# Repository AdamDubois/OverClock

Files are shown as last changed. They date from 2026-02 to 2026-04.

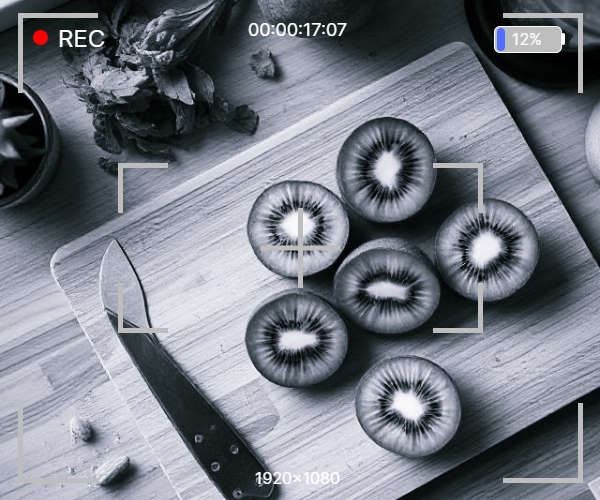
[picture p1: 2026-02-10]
Code/Codes_RaspPi/0-Desuet/Desuet_Codes_Test_RaspPi/img/imgKiwi.jpg

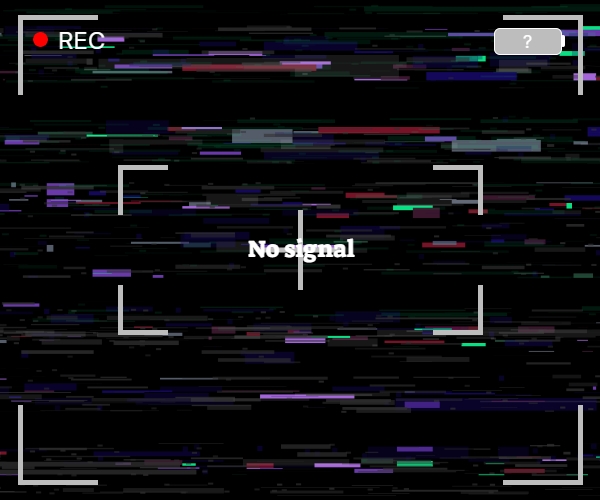
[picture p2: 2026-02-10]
Code/Codes_RaspPi/0-Desuet/Desuet_Codes_Test_RaspPi/img/NoSignal.jpg

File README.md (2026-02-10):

# Projet Bombe - InXtremis

## Description

Le projet Bombe à pour but de simuler une bombe pour un jeu d'évasion (escape game). Le joueur doit désamorcer la bombe en résolvant une série d'énigmes avant que le temps ne soit écoulé. Pour l'instant, le projet est en cours de développement et ne dispose pas encore de fonctionnalités complètes. Certains éléments de base ont été mis en place, mais ne sont pas intégrés dans un système de jeu complet. Par exemple, le contrôleur des lecteurs de cartes RFID est complètement fonctionnel et le contrôleur principal peut recevoir les données des lecteurs de cartes, mais il n'y a pas encore de logique de jeu pour utiliser ces données.

## Logique des composantes utilisées

**Contrôleur principal** : Il s'agit d'un Raspberry Pi 4 qui gère l'ensemble du système. Il reçoit les données des lecteurs de cartes RFID, des entrées/sorties (switchs et boutons) et peut contrôler d'autres composants tels que les LED, les buzzers, etc. Il est également responsable de la logique de jeu, c'est-à-dire de déterminer si les conditions pour désamorcer la bombe sont remplies ou non. Il gère également l'interface utilisateur qui sera sur un écran HDMI.

**Contrôleurs secondaires** : Il s'agit de trois ESP32-C3-WROOM-02U. Ils sont utilisés pour gérer la partie matérielle de la bombe, notamment les lecteurs de cartes RFID, les switchs, les boutons et les strips de DELs programmables. Ils communiquent avec le contrôleur principal via une I2C pour transmettre les données des entrées/sorties et recevoir les commandes pour contrôler les LED et autres composants.

## Fonctionnalités des différents ESP32

**ESP "RFID"** : Ce contrôleur est dédié à la gestion des lecteurs de cartes RFID. Il lit les données des cartes RFID et les transmet au contrôleur principal via I2C quand le Raspberry Pi en fait la demande.

**ESP "IO"** : Ce contrôleur gère les switchs et les boutons. Il lit l'état de ces entrées et les transmet au contrôleur principal via I2C quand le Raspberry Pi en fait la demande.

**ESP "LED"** : Ce contrôleur est responsable de la gestion des strips de DELs programmables. Il reçoit les commandes du contrôleur principal via I2C pour contrôler les LED en fonction de la logique de jeu.

## Architecture de ce dossier

Ce dossier contient les fichiers de code pour les différents composants du projet Bombe. Il est organisé de la manière suivante :
- `Code/` : Contient tous les fichiers de code pour les différents composants du projet, y compris le code pour le contrôleur principal (Raspberry Pi) et les contrôleurs secondaires (ESP32). Chaque composant a son propre sous-dossier pour organiser les fichiers de manière claire.
- `Documentation/` : Contient tous les documents liés au projet, tels que les diagrammes d'architecture, les schémas de câblage, les instructions d'installation et d'utilisation, les schémas électiques d'Altium, etc.
- `Matériel/` :  Contient les fichiers liés au matériel utilisé dans le projet, tels que les listes de composants, les schémas de câblage, les modèles 3D des boîtiers, etc.

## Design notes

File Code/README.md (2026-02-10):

# Projet Bombe - Code

## Description

Ce dossier contient tous les fichier de code pour les différents composants du projet. Il contient le code pour le contrôleur principal (Raspberry Pi) et les contrôleurs secondaires (ESP32). Chaque composant a son propre sous-dossier pour organiser les fichiers de manière claire.

## Architecture de ce dossier

Ce dossier contient les fichiers de code pour les différents composants du projet Bombe. Il est organisé de la manière suivante :
- `Codes_ESP32/` : Contient tous les fichiers de code pour les différents composants du projet, y compris le code pour le contrôleur principal (Raspberry Pi) et les contrôleurs secondaires (ESP32). Chaque composant a son propre sous-dossier pour organiser les fichiers de manière claire.
- `Codes_RaspPi/` : Contient tous les documents liés au projet, tels que les diagrammes d'architecture, les schémas de câblage, les instructions d'installation et d'utilisation, les schémas électiques d'Altium, etc.

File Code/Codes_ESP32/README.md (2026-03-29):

# Projet Bombe - Code/Codes_ESP32

## Description
Ce dossier contient les fichiers de code pour les différents ESP32 utilisés dans le projet Bombe. Chaque ESP32 a son propre sous-dossier pour organiser les fichiers de manière claire. Les codes sont écrits en C++ et utilisent la plateforme de développement PlatformIO pour faciliter la gestion des dépendances et la compilation.

## Architecture de ce dossier

Ce dossier contient les fichiers de code pour les différents composants du projet Bombe. Il est organisé de la manière suivante :
- `0-Desuet/` : Contient tous les projets de code qui ne sont plus utilisés ou qui sont obsolètes. Ces projets ont été créés avec un autre ESP comme base. Ils sont conservés à des fins de référence, mais ne sont plus maintenus ni utilisés dans le projet actuel.
- `ESP32_WROOM/` : Contient tous les projets de code pour les ESP32-WROOM utilisés dans le projet. Ces projets sont, pour la plupart, actifs et maintenus, et sont utilisés pour gérer les différentes fonctionnalités du projet Bombe, telles que la gestion des lecteurs de cartes RFID, des switchs, des boutons et des strips de DELs programmables. Chaque projet est organisé de manière claire pour faciliter la navigation et la compréhension du code.

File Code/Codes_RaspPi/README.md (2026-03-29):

# Projet Bombe - Code/Codes_RaspPi

## Description

Ici se trouvent tous les fichiers de code utilisés par le Raspberry Pi dans le projet Bombe.

## Architecture de ce dossier

Ce dossier contient les fichiers de code pour les différents composants du projet Bombe. Il est organisé de la manière suivante :
- `0-Desuet/` : Contient les codes qui ont été fait avant de choisir qu'on allait utiliser les ESP32. Ces codes sont donc fait pour communiquer avec tous les composants du projet, mais ils sont désuets et ne sont plus utilisés. Ils sont cependant gardés pour référence.
- `9Avril/` : Contient les projets de code qui seront utilisés pour la journée entrepreneuriale du 9 avril. Ces projets peuvent diverger du projet final, car ils sont faits pour être fonctionnels rapidement et pour être présentés lors de la journée entrepreneuriale. Ils sont cependant maintenus et peuvent être utilisés comme base pour le projet final. Après la journée entrepreneuriale, ces projets seront probablement fusionnés avec les autres projets actifs ou déplacés dans le dossier `0-Desuet/` s'ils ne sont plus pertinents pour le projet final.
- `Codes_Interactions_ESP/` : Contient les codes pour les interactions entre le Raspberry Pi et les ESP32, notamment la communication I2C. Il y a des codes uniquement pour envoyer et recevoir des données sur le bus I2C et il y en a pour tester uniqement les animations de DEL programmables sur le ESP32_DEL.
- `Enigmes/` : Contient les codes pour les différentes énigmes du projet Bombe. Ces codes sont utilisés pour gérer la logique des énigmes, les interactions avec les utilisateurs et les différentes fonctionnalités associées à chaque énigme. Chaque énigme a son propre sous-dossier pour organiser les fichiers de manière claire et faciliter la navigation.
- `Qt/` : Contient les fichiers de code pour l'interface graphique développée avec PyQt5. Cette interface permet de visualiser les données en temps réel, d'afficher les logs et d'interagir avec le système de manière plus intuitive.

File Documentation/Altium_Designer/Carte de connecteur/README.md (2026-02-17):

# Projet Bombe - Documentation/Altium_Designer

## Description

Cette section de la documentation regroupe l'ensemble des fichiers de conception électrique et de PCB réalisés avec le logiciel Altium Designer.
## Architecture de ce dossier

Elle contient les éléments suivants :
- Les schémas électriques du projet
- Les fichiers PCB (routage)
- Le dossier Bibliothèques contenant les composante utilisées dans les schémas et PCB

Les composants standards utilisés dans ce projet proviennent de la bibliothèque externe **Celestial Altium Library**.

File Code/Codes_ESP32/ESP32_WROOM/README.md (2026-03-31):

# Projet Bombe - Code/Codes_ESP32/ESP32_WROOM

## Description

Ce dossier contient les fichiers de code pour tous les projets de code pour les ESP32-WROOM utilisés dans le projet Bombe. Ces projets sont actifs et maintenus, et sont utilisés pour gérer les différentes fonctionnalités du projet Bombe, telles que la gestion des lecteurs de cartes RFID, des switchs, des boutons et des strips de DELs programmables. Chaque projet est organisé de manière claire pour faciliter la navigation et la compréhension du code.

## Architecture de ce dossier

Ce dossier contient les fichiers de code pour les projets ESP32-WROOM. Il est organisé de la manière suivante :
- `0-Desuet/` : Contient les projets obsolètes ou non utilisés. Ces projets ne sont plus maintenus et ne sont pas utilisés dans le projet Bombe, mais ils sont conservés pour référence ou pour des besoins futurs.
- `1-Codes_Tests/` : Contient des projets de test pour les ESP32-WROOM. Ces projets sont utilisés pour tester différentes fonctionnalités des ESP32-WROOM avant de les intégrer dans les projets principaux. Ces projets de test sont importants pour s'assurer que les composants fonctionnent correctement avant de les utiliser dans les projets principaux.
- `ESP_NEO_9AVRIL/` : Contient le projet du ESP qui gère les strips de DELs programmables. Ce projet reçoit des commandes I2C du Raspberry Pi pour contrôler les animations des strips de DELs programmables, et utilise la bibliothèque FastLED pour gérer les animations des DELs.
- `ESP-IO/` : Contient le projet du ESP qui gère les entrées/sorties, telles que les switchs et les boutons. Il utilise un IO expander pour gérer les entrées/sorties, et communique avec le Raspberry Pi en I2C pour envoyer les données des switchs et des boutons.
- `ESP-RFID/` : Contient le projet du ESP qui gère les lecteurs de cartes RFID. Ce projet lit les données des cartes RFID et les envoie les valeurs de UID des cartes en I2C au Raspberry Pi, quand il reçoit une requête de ce dernier.

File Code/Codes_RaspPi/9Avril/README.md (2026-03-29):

# Projet Bombe - Code/Codes_RaspPi/9Avril

## Description

Ici se trouvent les fichiers de code utilisés par le Raspberry Pi pour la journée entrepreneuriale du 9 avril. Ces codes sont fait pour fonctionner rapidement pour être utilisé lors de la journée entrepreneuriale. Les enigmes seront peut-être différentes de celles finales. Après la journée entrepreneuriale, ces codes seront peut-être modifiés pour s'adapter à la version finale du projet Bombe ou seront déplacées dans le dossier désuet du projet Bombe.

## Architecture de ce dossier

Ce dossier contient les fichiers de code pour la journée entrepreneuriale du 9 avril, notamment pour les interactions entre le Raspberry Pi et les ESP32 du projet Bombe. Il est organisé de la manière suivante :
- `RFID/` : Dossier contenant les codes pour l'énigme des lecteurs RFID. Il contient les codes pour lire les données des lecteurs RFID connectés aux ESP32 via I2C et pour envoyer des commandes I2C aux ESP32_DEL pour tester les animations de DEL programmables.
- `Switch/` : Dossier contenant les codes pour l'énigme des interrupteurs. Il contient les codes pour lire les données des interrupteurs connectés aux ESP32 via I2C et pour envoyer des commandes I2C aux ESP32_DEL pour tester les animations de DEL programmables.

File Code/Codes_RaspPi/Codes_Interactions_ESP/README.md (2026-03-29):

# Projet Bombe - Code/Codes_RaspPi/Codes_Interactions_ESP

## Description

Ici se trouvent les fichiers de code utilisés par le Raspberry Pi pour interagir avec les ESP32 du projet Bombe, notamment pour la communication I2C et les tests d'animations de DEL programmables sur le ESP32_DEL.

## Architecture de ce dossier

Ce dossier contient les fichiers de code pour les interactions entre le Raspberry Pi et les ESP32 du projet Bombe. Il est organisé de la manière suivante :
- `commande_I2C_test_led.py` : Code de test pour envoyer des commandes I2C au ESP32_DEL afin de tester les animations de DEL programmables. Utile pour vérifier que les commandes I2C sont correctement reçues et interprétées par le ESP32_DEL et que toutes les DELs fonctionnent correctement.
- `commandes_I2C.py` : Code qui permet d'envoyer ou demander des données à tous les ESP32 présents sur le bus I2C. Il suffit de spécifier l'adresse de l'ESP32 et la commande à envoyer. Utile pour envoyer des commandes spécifiques à un ESP32 ou pour demander des données à un ESP32 particulier de façon à s'assurer que la communication I2C fonctionne correctement avec chaque ESP32 individuellement.
- `read_RFID_I2C.py` : Code pour lire les données des lecteurs RFID connectés aux ESP32 via I2C. Lit les données en permanence et les affiche dans la console. Utile pour vérifier que les données des lecteurs RFID sont correctement reçues par le Raspberry Pi.
- `test_vitesse_IO.py` : Code de test pour mesurer la vitesse de lecture des données des ESP32 via I2C. Lit les données en permanence et affiche le temps de lecture dans la console. Utile pour vérifier que la communication I2C est suffisamment rapide pour les besoins du projet Bombe, notamment pour les énigmes qui nécessitent une lecture rapide des données des ESP32.

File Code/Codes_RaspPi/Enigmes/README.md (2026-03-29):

# Projet Bombe - Code/Codes_RaspPi/Enigmes

## Description

Contient les codes pour les différentes énigmes du projet Bombe. Ces codes sont utilisés pour gérer la logique des énigmes, les interactions avec les utilisateurs et les différentes fonctionnalités associées à chaque énigme. Chaque énigme a son propre sous-dossier pour organiser les fichiers de manière claire et faciliter la navigation.

## Architecture de ce dossier

Ce dossier contient les fichiers de code pour les différentes énigmes du projet Bombe, notamment pour les interactions entre le Raspberry Pi et les ESP32 du projet Bombe. Il est organisé de la manière suivante :
- `1/` : Dossier contenant les codes pour la première énigme du projet Bombe, qui est l'énigme des interrupteurs. Il contient les codes pour lire les données des interrupteurs connectés aux ESP32 via I2C et pour envoyer des commandes I2C aux ESP32_DEL pour tester les animations de DEL programmables.
- `2/` : Dossier contenant les codes pour la deuxième énigme du projet Bombe, qui est l'énigme des boutons et des strips de del ou il faut mettre les strips d'une couleur spécifique en fonction des boutons appuyés. Il contient les codes pour lire les données des boutons connectés aux ESP32 via I2C et pour envoyer des commandes I2C aux ESP32_DEL pour tester les animations de DEL programmables.

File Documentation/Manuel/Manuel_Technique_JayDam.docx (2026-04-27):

Adam Dubois

Jérémy Breault

Groupe: 2317

OverClock

Manuel technique présenté à :

Benoit Beaulieu

Louis-Philippe Gauthier

Simon Mailhot-Hébert

Étienne Desbiens

Département du génie électrique

Pour le cours

Projet de fin d’études

Cégep de Sherbrooke

2026-04-14

# 1. Description générale du produit

Ce projet consiste à la réalisation d’une mallette interactive qui intègre plusieurs dispositifs électroniques dans le but de proposer des énigmes à résoudre pour les utilisateurs. L’utilisateur devra interagir avec le système électronique et des composants physiques tout en étant guidé par une interface graphique à travers les jeux. Notre premier client est une entreprise de jeux d’évasion (InXtremis) qui propose différents scénarios dans la région de Sherbrooke. L’idée est de lui concevoir une mallette qui vient remplacer une mallette déjà existante, mais qui est endommagée et ne respecte plus les critères. Cette mallette est ajoutée à un module composé des trois barils et d’une structure en métal conçu par le client qui représente un module explosif simulé. Pour ce projet, les joueurs devront tenter leur chance et tester leur habilitées dans le but de résoudre différentes énigmes pour réussir à désamorcer un dispositif explosif simuler dans un temps allouer. La mallette agit comme élément central en structurant tous les modules ensemble. Placer au centre du produit, elle est le cerveau pour le fonctionnement du jeu, mais aussi un dispositif important pour aider les joueurs à mieux comprendre les énigmes tout en améliorant l’immersion.

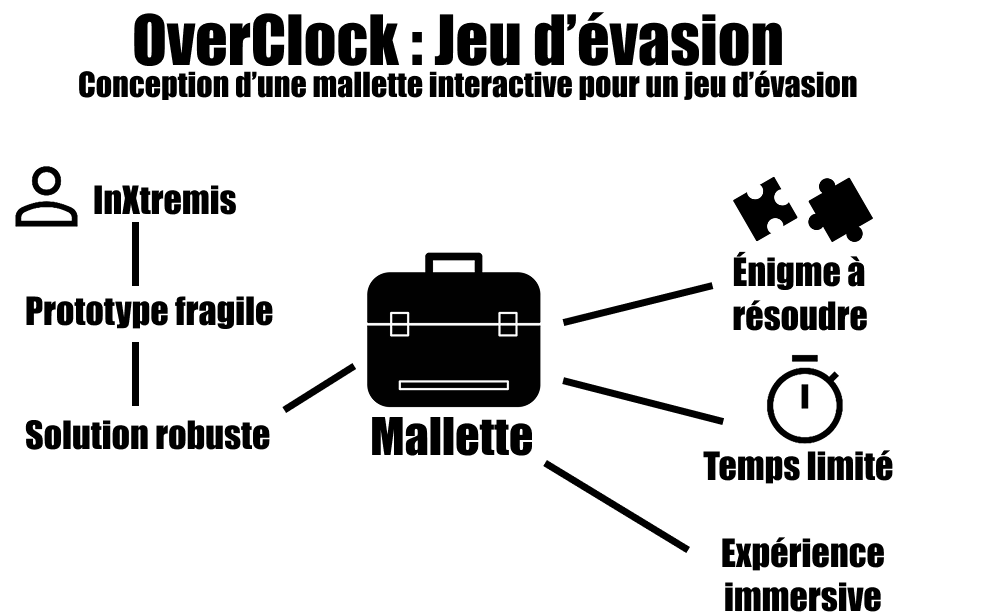
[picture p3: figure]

Figure 1 Vue d’ensemble du projet

# 2. Fonctionnement du produit

Le fonctionnement du projet est divisé en trois grandes parties. Nous avons le cerveau principal du projet, un Raspberry Pi 4, qui dirige les opérations à travers les différentes parties. Ensuite, trois ESP32 sont utilisés pour contrôler les différents modules composant les énigmes et pour finir, un écran HDMI est utilisé pour l’affichage de l’interface et pour faciliter le dépannage en cas de problème.

Le Raspberry Pi 4 envoie les directives à tous les modules connecter. Il contrôle l’écran via une communication HDMI et contrôle les trois ESP32 avec une communication de protocole I2C.

Le projet utilise trois ESP32 pour diriger différentes parties du module. Un ESP32 s’occupe du contrôle de toutes les bandes lumineuses. Un autre ESP32 s’occupe du contrôle des entrées des utilisateurs. Il contrôle les cinq boutons présents à l’intérieur de la mallette, les sept connecteurs banane et les quatre interrupteurs présents sur le module. Le dernier ESP32 s’occupe des quatre modules RFID. Le fonctionnement global repose sur une communication avec le Raspberry Pi 4. Chacun utilise le protocole I2C pour recevoir des commandes du Raspberry Pi 4. Le Raspberry Pi 4 agit comme maitre, tandis que les ESP32 agissent comme esclaves.

L’écran à l’intérieur de la mallette permet d’afficher le système d’exploitation du Raspberry Pi. Cet écran permet d’offrir une façon simple pour diagnostiquer un problème dans le Pi, mais permet aussi de venir changer le code pour les énigmes.

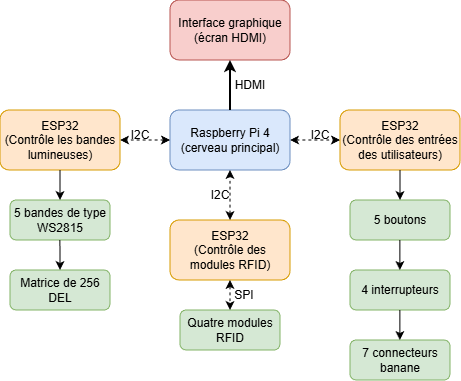
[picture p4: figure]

Figure 2 Diagramme de fonctionnement du projet

# 3. Procédure d’installation et d’opération

## Assemblage

1. Assembler les tuyaux de métal en fonction des numéros inscrits dessus.
2. Mettre les modules d’énigmes au bon emplacement en fonction des numéros.
3. Il faut mettre les barils à l’intérieur du châssis avant de le refermer complètement.
4. Passer tous les fils autour de la bombe de façon à tous les amener dans la mallette par le trou arrière.

## Branchement

Tous les câbles sont identifiés par un collant pour indiquer dans quel connecteur ils vont. Brancher tous les câbles à la bonne place sur la carte de connectique.

## Utilisation

Mettre l’interrupteur de l’alimentation principale (power supply) sur « I », puis activer la carte de connectique en position « ON ». Le système devrait alors s’alimenter et l’écran s’allumer automatiquement, avec le jeu en mode « Idle ». Pour lancer le jeu, il suffit d’envoyer une commande en UDP (à définir). Pour passer une énigme, appuyer trois fois sur le bouton vert en maintenant chaque appui pendant cinq secondes. Pour activer le mode débogage, appuyer cinq fois sur le bouton vert, toujours en maintenant chaque appui pendant cinq secondes.

## Dépannage

### Aucun démarrage

1. Vérifier que l’alimentation est bien fonctionnelle et sur la position « I ».
2. Vérifier que la carte de connecteur dans la mallette est bien à « ON ».
3. Vérifier la présence des trois indicatifs lumineux d’alimentation sur la carte de connecteur.
4. Tester chacun des fusibles présents sur la carte de connecteur.
5. Vérifier les connexions électriques des alimentations.
6. Remplacer l’alimentation avec une autre de 500 watts et plus si nécessaire.

### Écran non fonctionnel

1. Vérifier l’alimentation de l’écran.
2. Vérifier le câble HDMI.
3. Prendre un autre écran pour tester si nécessaire.

# 4. Contenu matériel

## Schéma électrique

La partie électronique du projet est composée de deux cartes électroniques. Nous avons la première carte qui s’occupe de raccorder tous les modules ensemble avec l’aide de plusieurs connecteurs. Celle-ci est située à l’intérieur de la mallette et représente la carte mère du projet. La deuxième carte est plus petite et s’occupe du branchement des quatre modules RFID. Elle est connectée à la carte mère avec deux câbles Ethernet (RJ45).

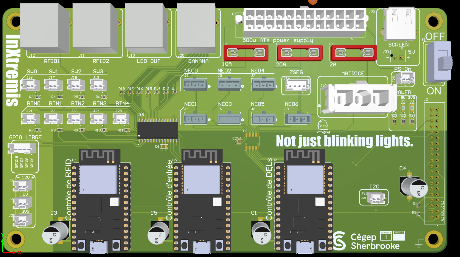
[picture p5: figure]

## Carte de connecteur

Figure 3 Carte mère

Le fonctionnement de la carte de connecteur repose sur cinq parties. La présente section passera à travers les parties pour vous expliquer le fonctionnement.

### Alimentation

L’alimentation du projet repose sur une alimentation ATX d’ordinateur d’une puissance de 500W et plus. Nous utilisons seulement le connecteur 24 broches, les sortie 3.3 volts, 5 volts ainsi que 12 volts pour l’alimentation des modules.

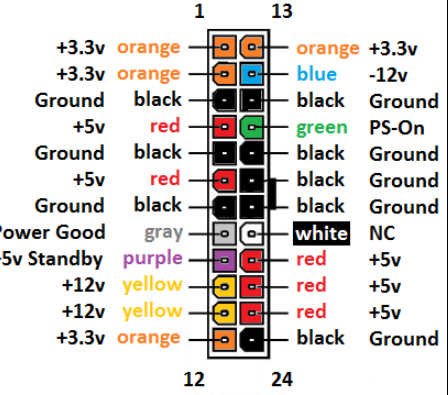
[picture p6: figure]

Figure 4 Répartition des broches – alimentation ATX

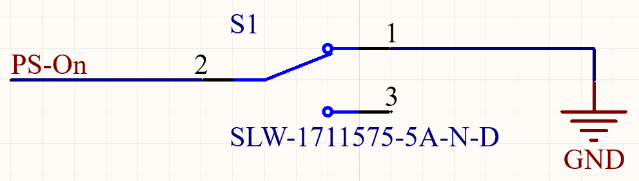
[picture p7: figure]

Le signal PS-ON nous permet de contrôler le fonctionnement de l’alimentation ATX. Si le signal est relié à la masse (GND), l’alimentation s’active. Les signaux 5 VUSB, PG, -5 V, et -12 V ne sont pas utiliser dans ce projet.

Figure 5 Interrupteur d’alimentation du système

Puisque le projet nécessite une grande puissance pour l’alimentation des bandes lumineuse, il est important de respecter la contrainte concernant les fusibles. Trois valeurs de fusible sont utilisées.

- 2 A pour la ligne 3,3 V;
- 10 A pour la ligne 12 V;
- 20 A pour la ligne 5 V;

Figure 6 Position des fusibles sur la carte

L’alimentation 12 V permet de fournir l’électricité aux six bandes lumineuses de type WS2815. L’alimentation 5 V alimentent les trois ESP32, le Raspberry Pi, la grande matrice de Del, le convertisseur de niveau logique et l’écran HDMI. L’alimentation 3.3 V alimente les quatre modules RFID et les différentes résistances de tirage vers le haut.

### Raspberry Pi

Le Raspberry Pi est connecté à la carte électronique via un câble nappe (ribbon câble) relié à un connecteur 40 broches. La communication avec les trois modules ESP32 s’effectue à l’aide du protocole I²C, permettant au Raspberry Pi d’envoyer des requêtes à chacun des dispositifs.

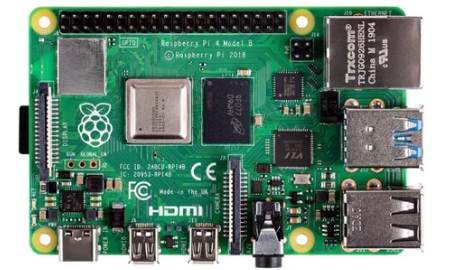
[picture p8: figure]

Figure 7 Raspberry Pi 4

### Esp32_Wroom (Contrôle de Del)

Le contrôle des bandes de DEL utilisées dans le projet est assuré par un ESP32 dédié. Celui-ci fonctionne comme esclave sur le bus I²C, avec l’adresse 0x12.

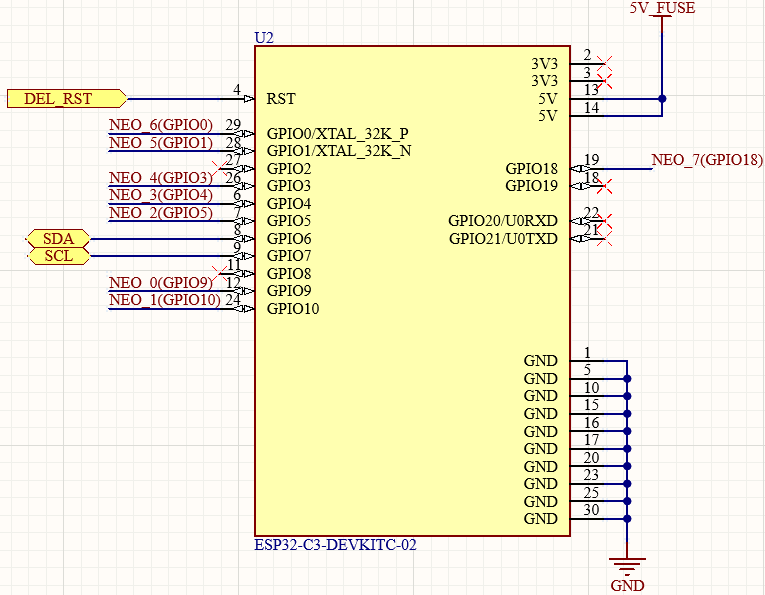
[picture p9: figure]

Figure 8 Schéma électrique de l’ESP32 pour le contrôle des bandes DEL

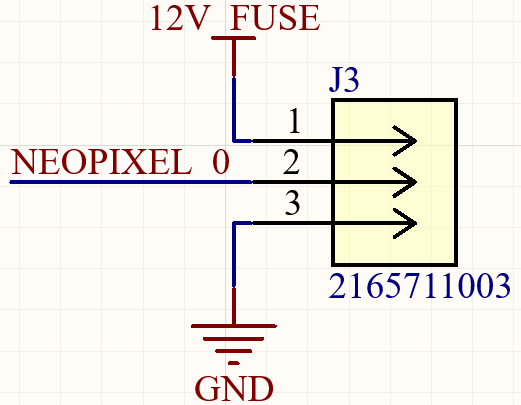
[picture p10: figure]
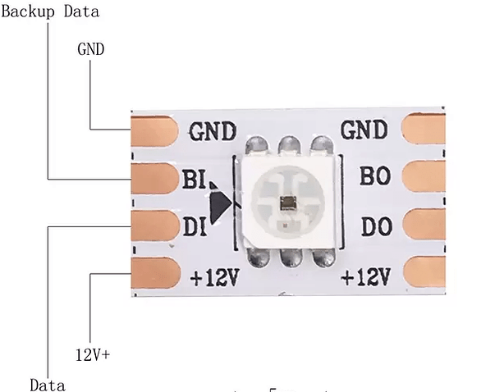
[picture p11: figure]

Les bandes DEL sont en 12 V avec un signal de données en 5 V, donc un convertisseur de niveau logique est utilisé pour les contrôler avec le contrôleur en 3,3 V.

Figure 9 Configuration des broches des WS2815

Sur le schéma de gauche, la configuration des broches pour le fonctionnement des bandes DEL (WS2815) montre le câblage pour leur fonctionnement. On peut voir se l’image de droite que nous avons seulement un connecteur de trois broches, cela est normal, puisque les signaux GND et Backup Data sont reliés ensemble.

### Esp32_Wroom (Contrôle de RFID)

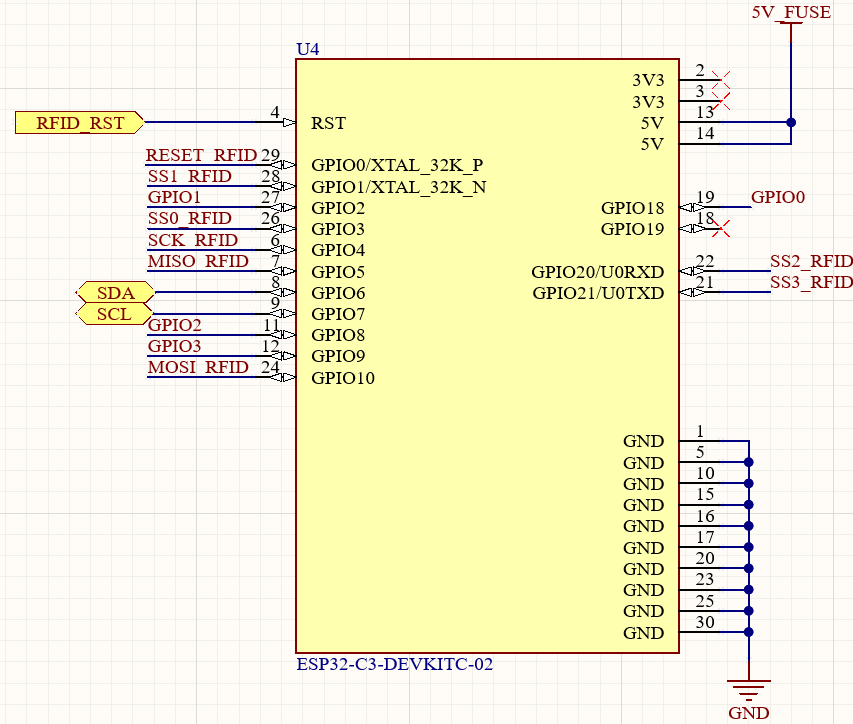
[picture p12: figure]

Le contrôle des quatre modules RFID est assuré par un ESP32 dédié. Celui-ci fonctionne comme esclave sur le bus I²C, avec l’adresse 0x11

Figure 10 Schéma électrique de l’ESP32 pour le contrôle des modules RFID

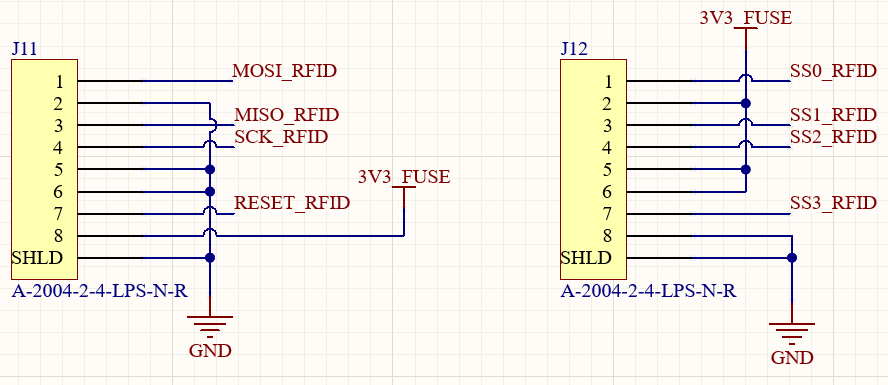
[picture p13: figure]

Les modules RFID sont connectés à une carte intermédiaire. Cette carte est ensuite reliée à notre carte principale avec deux câbles RJ45. Les câbles servent à la fois pour la communication et l’alimentation, en utilisant les paires torsadées pour réduire les interférences.

Figure 11 Câblage des signaux en paires torsadées

### Esp32_Wroom (Contrôle d’entrée)

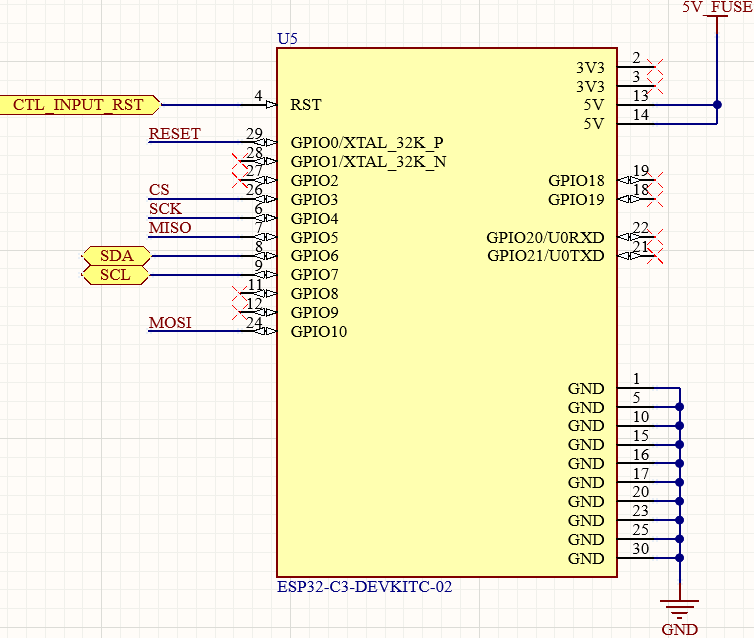
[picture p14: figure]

La gestion de toutes les entrées (boutons, interrupteurs et connecteurs) est assurée par un ESP32, qui en effectue la lecture. Celui-ci fonctionne comme esclave sur le bus I²C, avec l’adresse 0x10.

Figure 12 Schéma électrique de l’ESP32 pour le contrôle des entrées

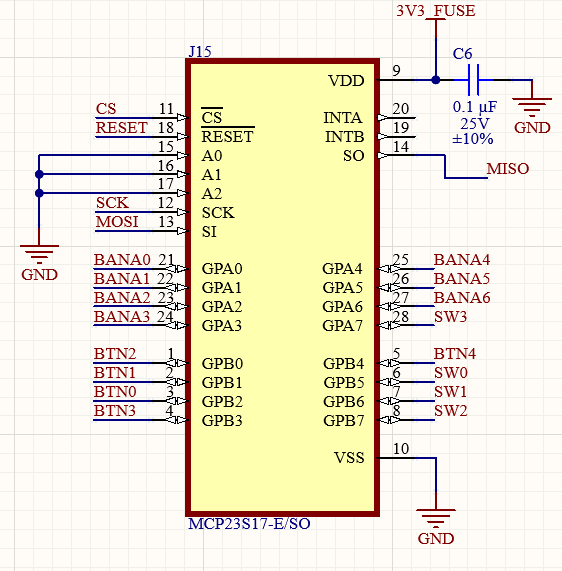
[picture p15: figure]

Comme il n’y a pas assez de GPIO sur le contrôleur, un expanseur est utilisé pour en ajouter 16 de plus. Il communique en SPI.

Figure 13 Expanseur 16 GPIO

Les cinq boutons présents à l’intérieur de la mallette ainsi que les quatre interrupteurs utilisent des connecteurs de type JST pour être raccordés à la carte de connexion.

Les connecteurs bananes sont raccordés à l’aide d’un câble RJ45.

Figure 14 Connecteurs des boutons et interrupteurs

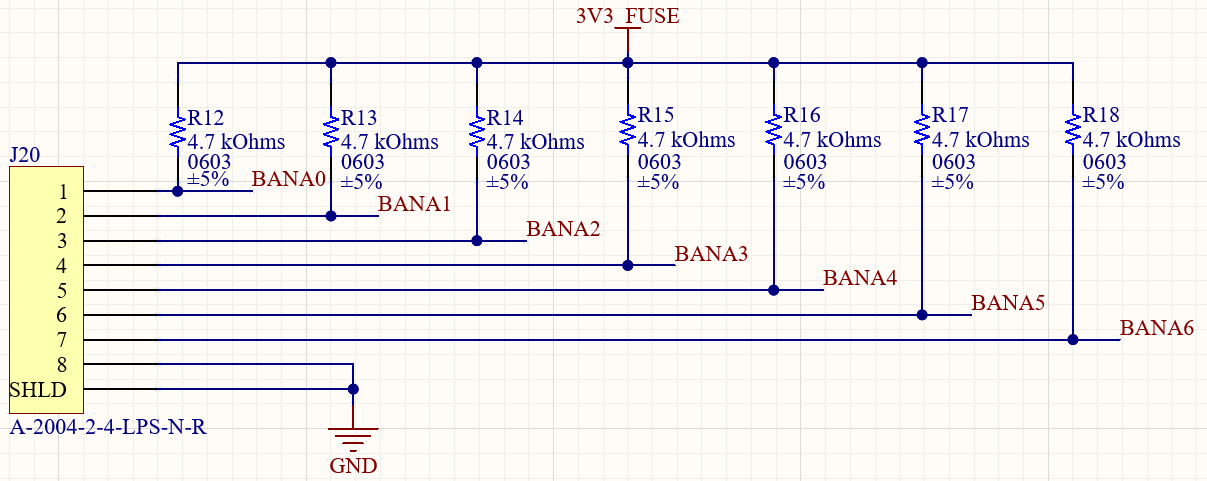
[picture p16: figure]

Figure 15 Connecteurs banane

## Carte pour module RFID

La deuxième carte pour le raccordement des quatre modules RFID est un moyen simple de nous permettre de venir diminuer le nombre de câbles qui doivent rejoindre la carte principale à l’intérieur de la mallette. Il connecte les deux câbles RJ45 et sépare le branchement pour venir raccorder les quatre modules proprement.

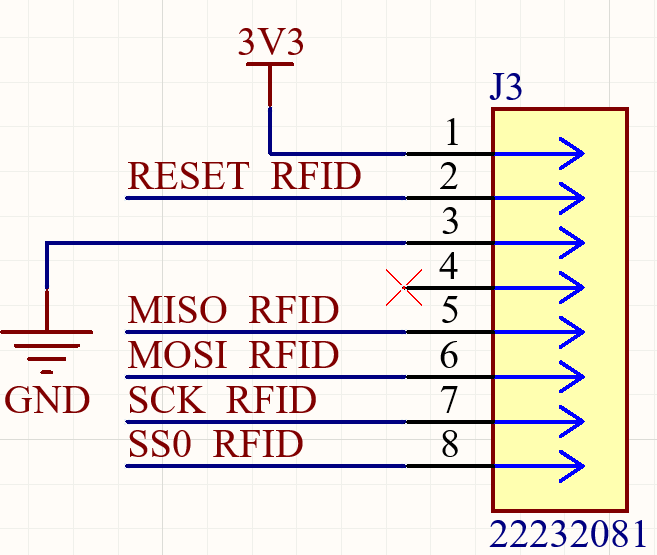
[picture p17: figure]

Figure 16 Câblage des modules RFID

L’alimentation de la carte provient de la ligne principale 3,3 V. Pour vérifier le bon fonctionnement, un indicateur lumineux est présent sur la carte afin de confirmer la présence de l’alimentation sur la carte.

# 5. Contenu logiciel

Pour obtenir plus d’information sur le contenu logiciel, simplement vous rendre sur la page git du projet.

Lien git : https://github.com/AdamDubois/OverClock.git

# 6. Procédure de développement

## Raspberry Pi

### Code

Dans cette partie, vous trouverez toutes les informations nécessaires pour modifier, exécuter et maintenir le code du projet. Le code est séparé en deux sections : le Raspberry Pi (maître du système) et les ESP32 (esclaves). La communication entre le Raspberry Pi et les ESP32 est effectuée via le protocole I2C.

Les fichiers sources sont disponibles sur le dépôt GitHub du projet :

Lien Git : https://github.com/AdamDubois/OverClock.git

1. Télécharger les fichiers sources (Git)

- Se rendre sur le dépôt GitHub du projet.
- Copier le lien du dépôt.
- Sur le Raspberry Pi (ou un ordinateur), cloner le dépôt :

git clone https://github.com/AdamDubois/OverClock.git

cd OverClock

Emplacements importants dans le dépôt :

- Code Raspberry Pi : Code/Codes_RaspPi/
- Code ESP32 : Code/Codes_ESP32/ESP32_WROOM/

2. Préparer le Raspberry Pi (installation des outils)

La partie Raspberry Pi est développée en Python. Avant d’exécuter les scripts, il faut installer les outils de base.

Mettre à jour le système :

sudo apt update

sudo apt upgrade -y

Installer les outils nécessaires :

sudo apt install -y git python3 python3-pip python3-venv

Activer l’I2C (si ce n’est pas déjà fait) :

- Ouvrir l’outil de configuration : sudo raspi-config
- Aller dans Interface Options → I2C → Enable
- Redémarrer le Raspberry Pi : sudo reboot

Vérifier que l’I2C est actif :

ls /dev/i2c*

Résultat attendu : /dev/i2c-1

3. Installer les librairies Python (requirements.txt)

Afin de standardiser l’installation des dépendances, un fichier requirements.txt est disponible au chemin suivant :

Code/Codes_RaspPi/requirements.txt

- Procédure d’installation

Se placer à la racine du dépôt :

cd /chemin/vers/OverClock

Créer un environnement virtuel Python (recommandé) :

python3 -m venv .venv

source .venv/bin/activate

pip install --upgrade pip

Installer les dépendances :

pip install -r Code/Codes_RaspPi/requirements.txt

4. Organisation du code Raspberry Pi

Le dossier Code/Codes_RaspPi/ est organisé en plusieurs sous-dossiers :

- Codes_Interactions_ESP/ : scripts de communication et tests (I2C, lecture RFID, reset ESP).
- Enigmes/ : logique des énigmes (ex. : Enigmes/1/, Enigmes/2/).
- 9Avril/ : version de démonstration/intégration (peut diverger de la version finale).

5. Exécuter des tests de communication (Raspberry Pi ↔ ESP32)

Les scripts de tests se trouvent dans :

Code/Codes_RaspPi/Codes_Interactions_ESP/

Test de communication I2C :

- Activer l’environnement virtuel : source .venv/bin/activate
- Aller au dossier : cd Code/Codes_RaspPi/Codes_Interactions_ESP
- Lancer : python3 commandes_I2C.py

Lecture RFID via I2C :

- Activer l’environnement virtuel : source .venv/bin/activate
- Aller au dossier : cd Code/Codes_RaspPi/Codes_Interactions_ESP
- Lancer: python3 read_RFID_I2C.py

6. Exécuter le code principal (Raspberry Pi)

Selon la version utilisée, le code d’intégration se trouve dans :

Code/Codes_RaspPi/9Avril/

Exemple d’exécution :

1. Activer l’environnement virtuel : source .venv/bin/activate
2. Se placer dans le dossier : cd Code/Codes_RaspPi/9Avril
3. Exécuter : python3 tout_v2.py

7. Développement ESP32 (compilation et téléversement)

Les projets ESP32 se trouvent dans :

Code/Codes_ESP32/ESP32_WROOM/

Projets principaux :

- ESP_NEO_9AVRIL/ : gestion des bandes DEL (commandes I2C reçues du Raspberry Pi).
- ESP-IO/ : gestion des entrées/sorties (boutons, interrupteurs, connecteurs bananes).
- ESP-RFID/ : gestion des lecteurs RFID (envoi des UID via I2C).
- 1-Codes_Tests/ : projets de test.
- Procédure générale
1. Ouvrir le projet dans Arduino IDE ou PlatformIO.
2. Sélectionner la carte ESP32-WROOM-C3-02U.
- Dans PlatformIO, le board est déjà choisi dans le projet. Pas besoin de lui spécifier une nouvelle fois.
3. Compiler le projet.
4. Téléverser via USB.
5. Vérifier la communication avec le Raspberry Pi à l’aide des scripts I2C ou regarder dans le terminal série si « DEBUG_MODE » est à « true » dans config.h.

8. Validation après modification

Après toute modification de code (Raspberry Pi ou ESP32), valider :

- Le Raspberry Pi démarre correctement.
- L’I2C est actif (/dev/i2c-1).
- Les ESP32 répondent via I2C.
- Les entrées fonctionnent (ESP-IO).
- Les DEL répondent correctement (ESP_NEO_9AVRIL).
- Les UID RFID remontent correctement (ESP-RFID).

### Interface

Dans cette partie, vous trouverez toutes les informations concernant la réalisation ainsi que le fonctionnement de l’interface graphique pour les énigmes

La conception de l’interface a été réaliser avec le langage de programmation QML sur l’application Qt Design Studio. Cette application est un environnement de développement d’interface graphique permettant à l’utilisateur qui l’utilise de concevoir son interface avec différent outil comme des composants visuels, des outils pour la mise en page et d’autres outils permettant la conception d’animation. L’utilisateur commence par créer un premier rendu de son interface et la programme ensuite. La présente partie vous guidera à travers l’installation de cette application exécutée sur un ordinateur.

#### Télécharger l’installateur Qt

  - Rendez-vous sur le site officiel de Qt pour créer votre compte avec une licence éducative Qt Educational Licenses (https://www.qt.io/development/qt-educational-license).
  - Connectez-vous sur le site Qt (https://www.qt.io/development/qt-educational-license).
  - Télécharger Qt Online Installer dans le portail Qt à la section downloads – Qt downloads.
  - Exécuter Qt Online Installer.
  - Suivez les étapes de l’installateur Qt.
    - Connectez-vous avec votre compte Qt.
    - Sélectionner le chemin pour l’installation de Qt.
    - Sélectionner Qt for desktop development et Custum Installation.
    - Dans le menu d’installation Visual Creation Tools, sélectionner Qt Design Studio 4.8.1.
    - Procéder à l’installation.

#### Premier pas avec l’application Qt Design Studio

  - Au lancement de l’application, vous aurez deux choix possibles, créé un nouveau projet ou ouvrir un projet existant. Pour l’instant, choisissez de créer un nouveau projet.
  - Dans les détails de la création du projet, il est important de choisir la bonne résolution pour l’affichage de son interface. Pour simplement tester, il est recommandé de mettre la même résolution que l’écran de son ordinateur ou de mettre plus petit.
  - Voici à quoi devrait ressembler votre fenêtre.

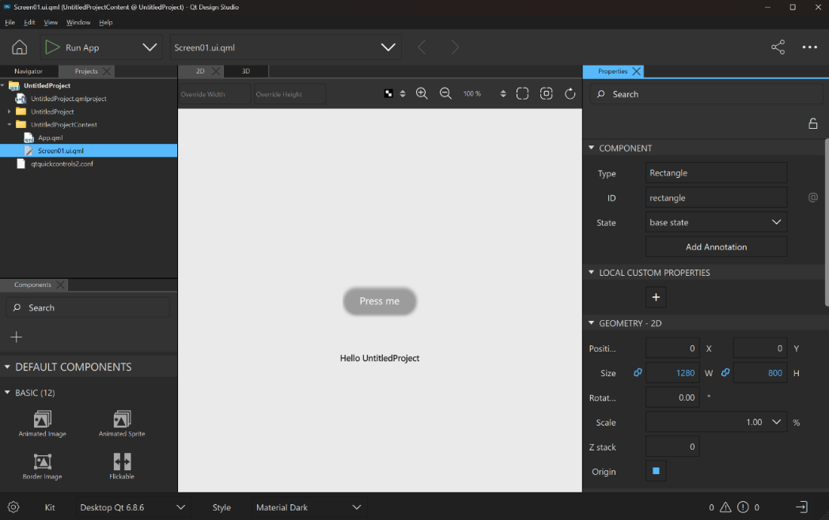
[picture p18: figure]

Figure 17 Écran initial Qt Design Studio

- Rendez-vous dans le ruban View en haut à gauche de la fenêtre et cocher Code dans le menu déroulant Views pour afficher le code de l’interface

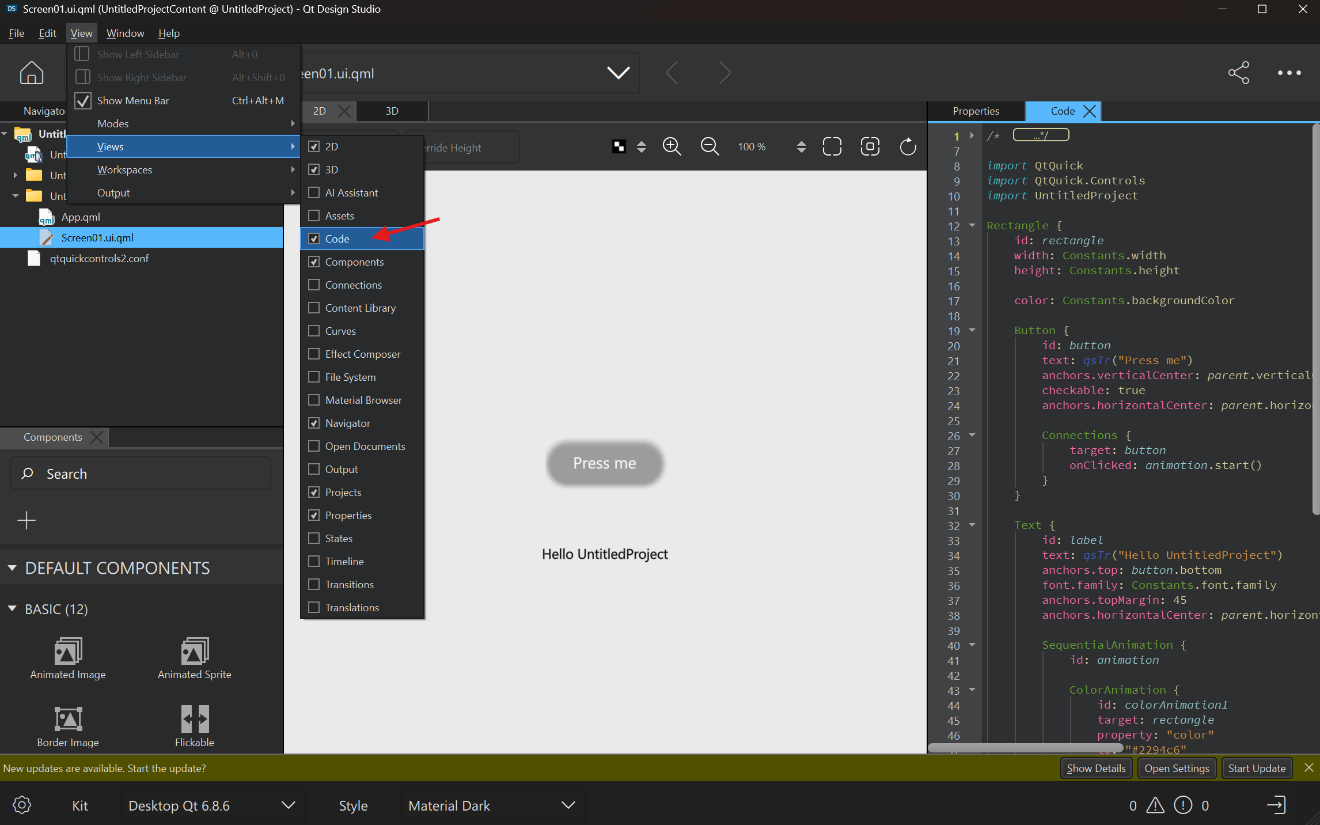
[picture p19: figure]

Figure 18 Afficher le code de l’interface

- La visualisation du code permet de voir comment les différents composants de l’interface sont représentés en langage de programmation QML. Cela nous permet de venir modifier des propriétés plus précisément. Je vous recommande d’aller consulter des exemples et tutoriels sur le site officiel de Qt (Qt Doc (https://doc.qt.io/qt-6/qtexamplesandtutorials.html)).
- Dans le bas à gauche de l’écran, vous trouverez tous les composants disponibles à la construction de votre interface.

Figure 19 Composants Qt

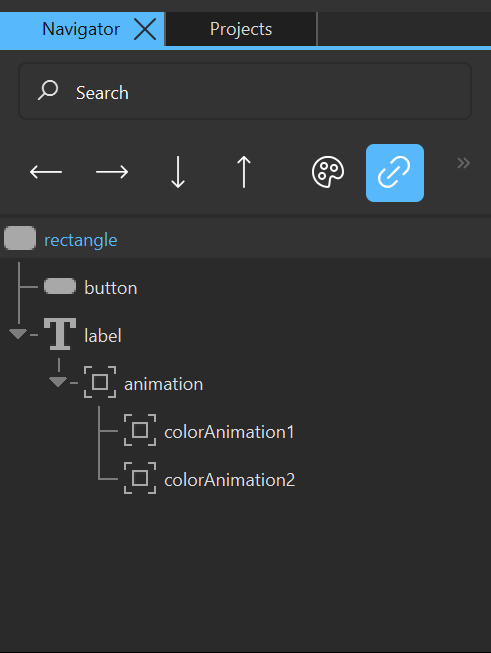
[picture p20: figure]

- Dans la section gauche de votre fenêtre, vous trouverez la section navigation qui permet de visualiser la structure hiérarchique de l’interface. Vous trouverez aussi la section projet qui permet de voir les différents fichiers de votre interface.

Figure 20 Structure Qt

- Vous pouvez tester votre première interface en cliquant sur le bouton Run App
- Vous êtes maintenant plus familiarisée avec l’application Qt Design Studio, je vous recommande maintenant de passer à l’étape suivante pour reprendre ou modifier le projet déjà existant

#### Utilisation du projet existant

Dans le dossier Git du projet, rendez-vous au chemin « OverClock\Code\Codes_RaspPi\Qt\Interface_9avril\OverClockUI\OverClock ». C’est ici que ce trouve tous les fichiers responsables au fonctionne de l’interface graphique pour le jeu d’évasion.

Vous pouvez ouvrir ce fichier dans Qt Design Studio.

Voici la liste des fichiers importants pour la modification ou la création du jeu.

- Le fichier main.py permet d’initialiser l’interface graphique et de structurer le fonctionnement de celle-ci en démarrant le serveur de réception de données (JsonReceive), puis lance l’interface. Il s’occupe de la réception des données du jeu pour les transmettre à l’interface.
- Le fichier jsonreceive.py permet de gérer la communication entre l’interface et les données envoyer par le Raspberry Pi comme, le démarrage du jeu, énigme, état des RFID. Il inclut un moniteur interne pour simuler le temps restant au jeu.
- Dans le dossier « OverClockContent », vous trouverez tous les fichiers pour la création de l’interface.
- Le fichier « App.qml » permet la gestion de l’affichage des différentes interfaces du jeu en fonction.
- Les fichiers commençant par le terme « Enigme », représente chacun une énigme en particulier.
- Le fichier « IdleScreen » est l’interface lors du démarrage et lorsque le jeu est inactif.
- Le fichier « FinScreen » est l’interface affichée lorsque le jeu est terminé.

Pour lancer l’interface, il suffit de lancer le fichier « main.py ».

#### Fonctionnement de l’interface sur le Raspberry Pi

Cette section vous montrera comment faire fonctionner l’interface sur le Raspberry Pi 4.

Pour faire fonctionner l’interface, il est nécessaire d’installer les bibliothèques requises sur le Raspberry Pi 4 à l’aide de la commande « sudo apt install ».

- libpyside6-py3-6.8
- python3-pyside6.qtqml
- Python3-pyside6.qtcore
- python3-pyside6.qtquick
- Python3-pyside6.qtopengl
- python3-pyside6.qtgui
- python3-pyside6.qtwidgets
- qml6-module-qtquick qml6-module-qtquick-window -y
- qml6-module-qtquick-controls qml6-module-qtquick-layouts -y
- qml6-module-qtquick-timeline -y

Il est recommandé de développer l’application sur un ordinateur plutôt que directement sur le Raspberry Pi 4.

# 7. Listes de matériel et coûts

Figure 21 Détail des coûts

# 8. Modifications et améliorations

1. Il manque un GPIO sur le PCB pour connecter le bouton vert de l’énigme des connecteurs bananes.
2. Le boitier contenant les lecteurs RFID est trop petit ce qui cause des interférences et empêche un lecteur fiable et durable des cartes RFID
3. Les connecteurs pour les bandes DEL ont été faites pour des bandes DEL de 3 connecteurs. Les bandes DEL qu’on utilise actuellement ont 4 connecteurs. Il faudrait donc changer ces connecteurs
4. Changer les connecteurs JST sur la carte pour des connecteurs MOLEX. Les JST sont assez difficile à assembler et sont beaucoup plus difficile à débrancher que des MOLEX.
5. Le bus RX et TX du ESP RFID est utilisé par des CS. Il est donc impossible de Serial Print des informations en même temps d’obtenir les valeurs des lecteurs.

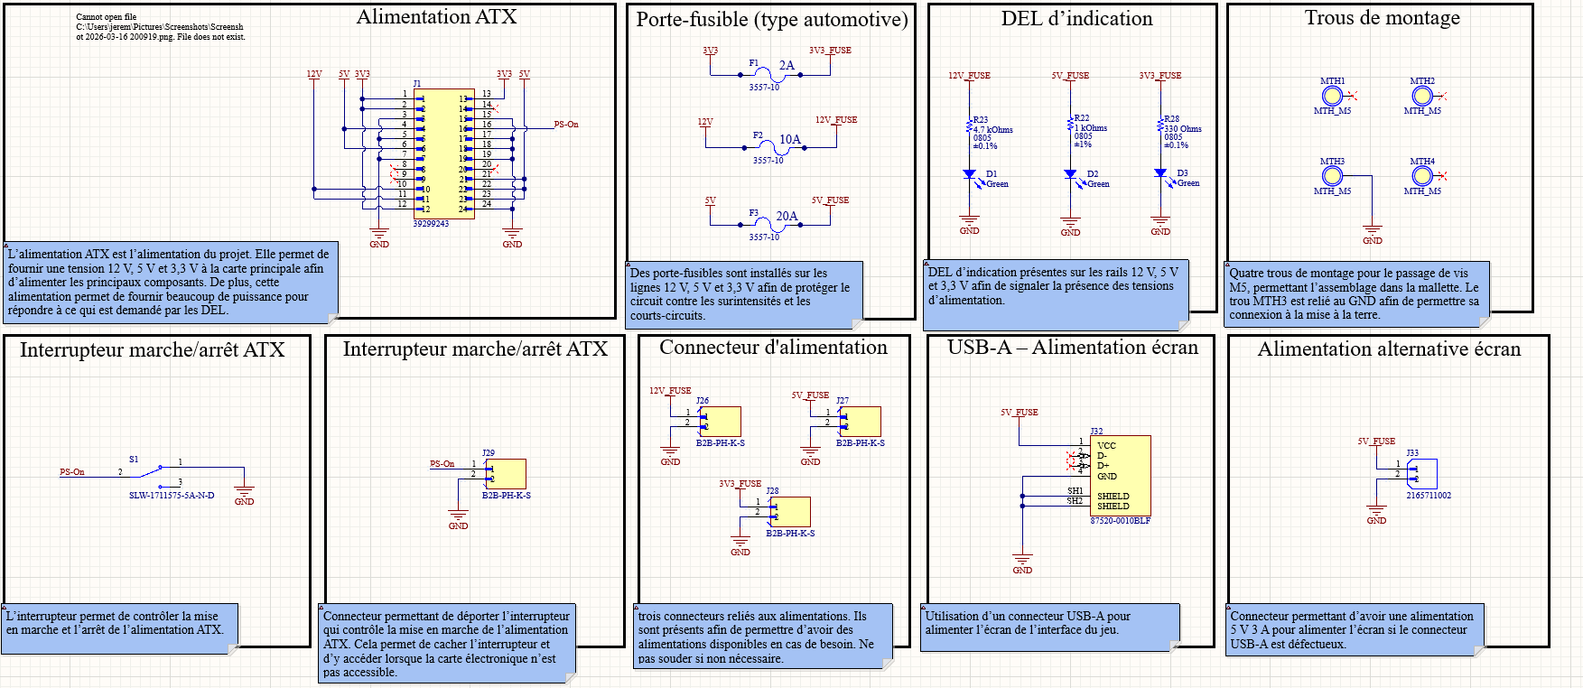
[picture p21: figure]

# Documents annexes

Figure 22 Alimentation

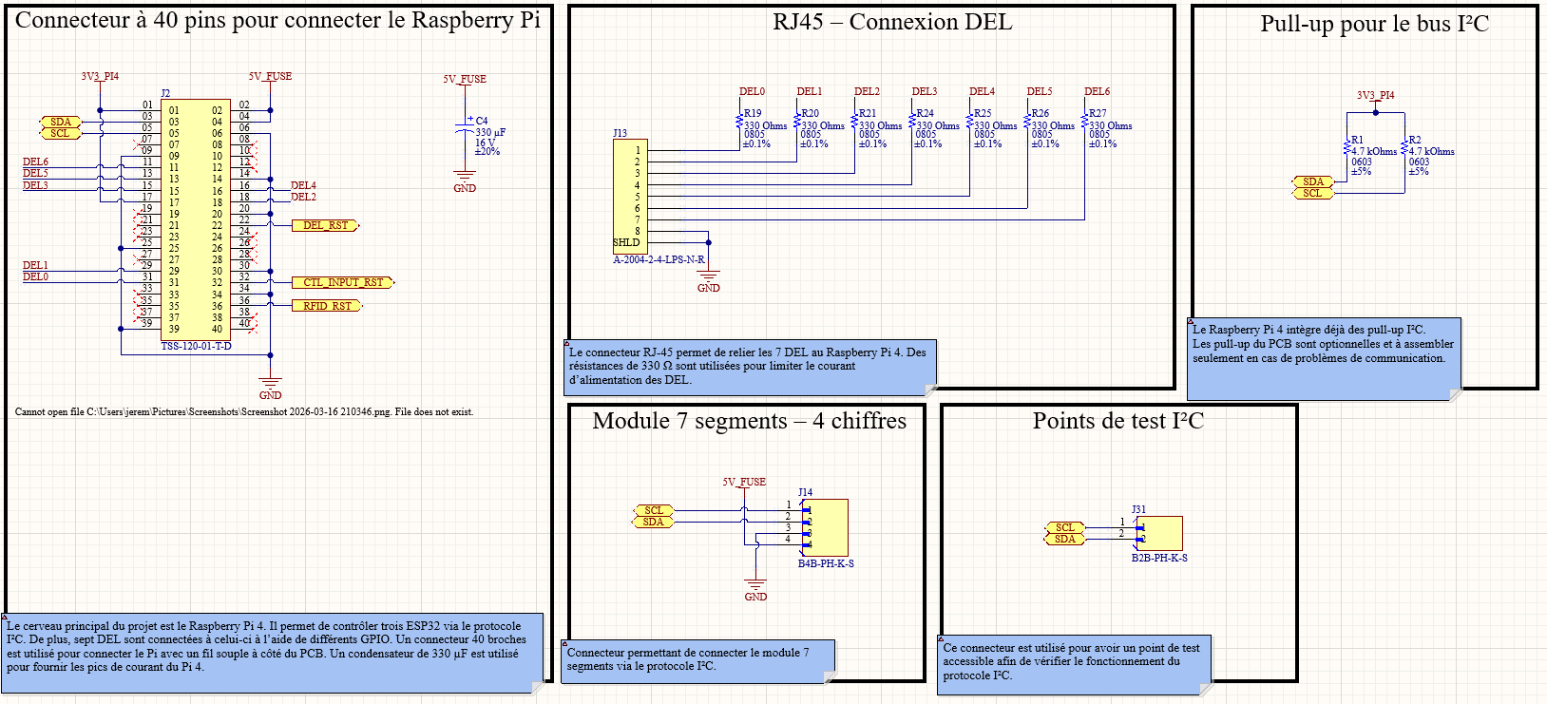
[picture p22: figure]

Figure 23 Raspberry Pi 4

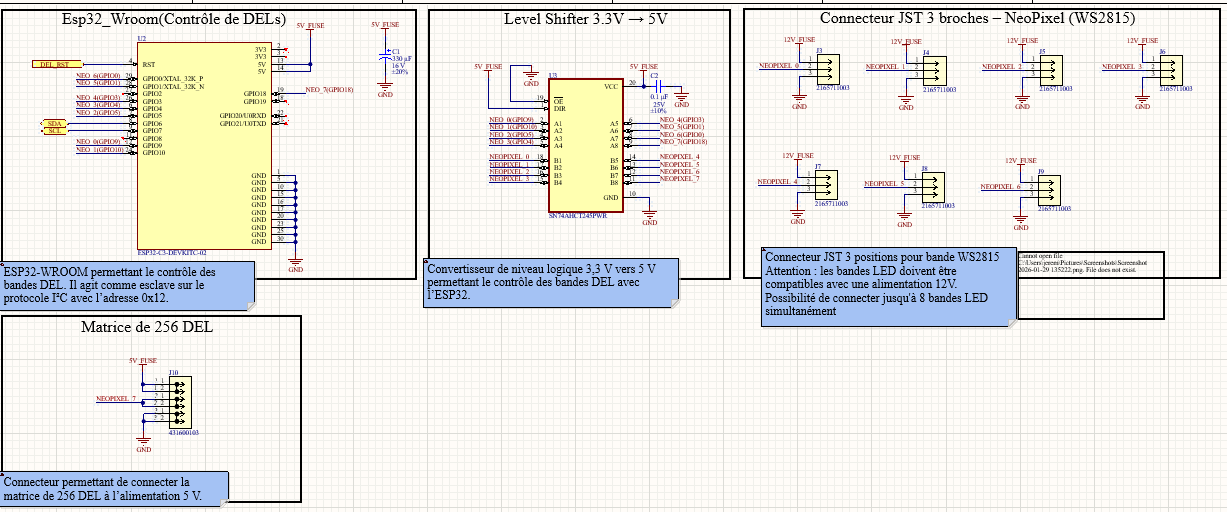
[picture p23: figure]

Figure 24 Contrôle de DEL

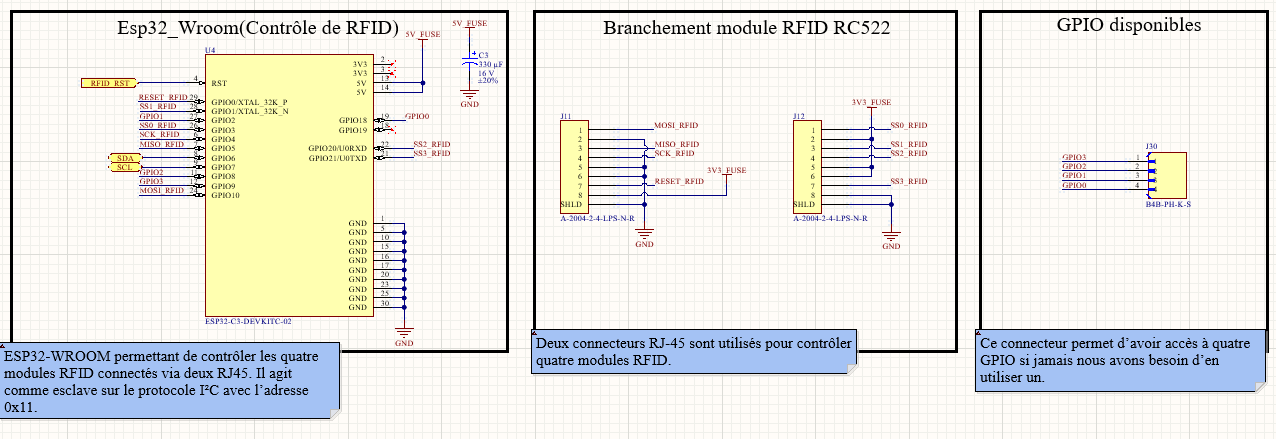
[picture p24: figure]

Figure 25 Contrôle de RFID

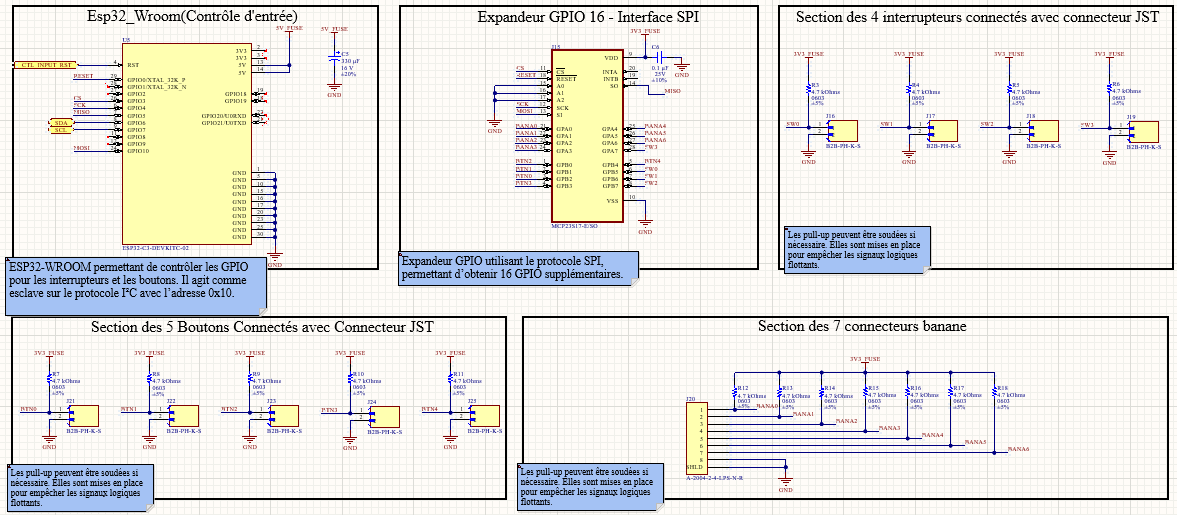
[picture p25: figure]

Figure 26 Contrôle d'entrée

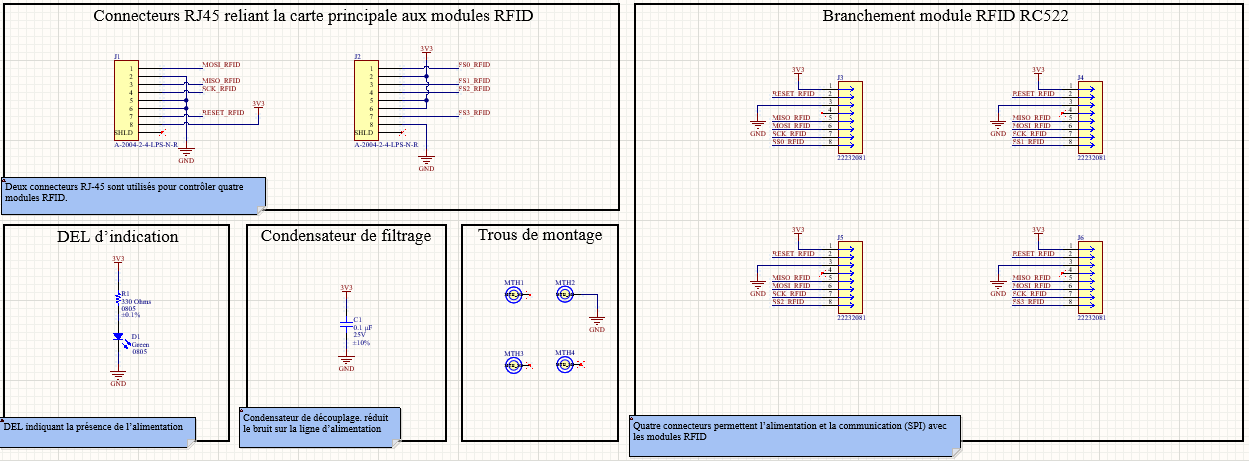
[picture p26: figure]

Figure 27 Carte RFID

Nom du Projet Manuel Technique

OverClock Manuel Technique

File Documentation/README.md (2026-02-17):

# Projet Bombe - Documentation

## Description

Ici vous trouverez tous les documents liés au projet Bombe, y compris les diagrammes d'architecture, les schémas de câblage, les instructions d'installation et d'utilisation, les schémas électiques d'Altium, etc. Ce dossier est destiné à fournir une documentation complète pour le projet Bombe afin de faciliter la compréhension et la mise en œuvre du projet pour tous les membres de l'équipe et les futurs contributeurs.

## Architecture de ce dossier

Ce dossier contient les fichiers de documentation pour les différents composants du projet Bombe. Il est organisé de la manière suivante :
- `Altium_Designer/` : Contiendra les schémas électriques et les PCB conçus avec Altium Designer pour les différents composants du projet.
- `Références/` : Contient toutes les références utiles à la compréhension du système et des schémas électriques (documents techniques, fiches techniques, notes, etc.).

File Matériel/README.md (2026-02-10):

# Projet Bombe - Matériel

## Description

Ce dossier contient les informations sur le matériel nécessaire pour réaliser le projet de la bombe. Il inclut les composants électroniques, les outils et les matériaux requis pour assembler et faire fonctionner la bombe.

## Architecture de ce dossier

Ce dossier contient les fichiers liés au matériel utilisé dans le projet Bombe. Il est organisé de la manière suivante :

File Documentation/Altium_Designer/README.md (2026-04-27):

# Projet Bombe - Altium Designer

## Description
Vous trouverez ici tous l'ensemble des fichiers liés à la conception électronique réalisée avec la plateforme Altium Designer 

Vous trouverez les schémas, les bibliothèques de composants, et les deux conceptions pour les cartes électroniques du projet.

## Structure du dossier
- Facture - contiens les factures reliées à la conception des cartes électroniques.
- Bibliothèques - regroupe les bibliothèques des composantes utilisées dans le projet.
- Carte de connecteur - tous les fichiers pour la conception de la carte électronique principale du projet.
- Carte RFID - contiens les fichiers pour la conception de la carte électronique pour le contrôle des modules RFID.

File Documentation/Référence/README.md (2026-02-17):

# Projet Bombe - Documentation/Référence

## Description

Ce dossier contient les documents techniques utilisés pour le projet :

## Architecture de ce dossier

Ce dossier contient les fichiers de documentation pour les différents composants du projet Bombe. Il est organisé de la manière suivante :
- Fiches techniques des composants
- Note utile pour la réalisation du projet
- Documents techniques

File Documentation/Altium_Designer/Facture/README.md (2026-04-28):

# Projet Bombe - Altium Designer/Facture
## Description
Vous trouverez ici les factures reliées à la conception des cartes électroniques du projet OverClock.

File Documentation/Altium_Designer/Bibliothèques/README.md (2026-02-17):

# Projet Bombe - Documentation/Altium_Designer/Bibliothèques

## Description

Ce dossier contient l’ensemble des bibliothèques utilisées pour le projet. Les composants sont organisés en différentes catégories.

Les composants standards utilisés dans ce projet proviennent de la bibliothèque externe **Celestial Altium Library**.

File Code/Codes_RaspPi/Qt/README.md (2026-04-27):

# Projet Bombe - Code/Code_RaspPi/Qt

## Description

Ce dossier contient le code Qt utilisé sur le Raspberry Pi pour tester l’interface graphique du projet Bombe.

Vous trouverez une première interface graphique pour les trois énigmes proposées à la soirée entrepreneuriales.

## Architecture de ce dossier

- test/ : contient une première version d’interface utilisateur très simple servant aux tests et à la validation de base.
- Interface_9avril : contient l'ensemble des fichiers pour le fonctionnement de l'interface graphique pour les trois énigmes proposées à la soirée entrepreneuriales.

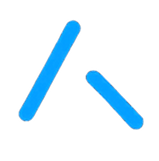
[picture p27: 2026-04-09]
Code/Codes_RaspPi/Qt/Interface_9avril/OverClockUI/OverClock/OverClockContent/images/deuxLignes.png

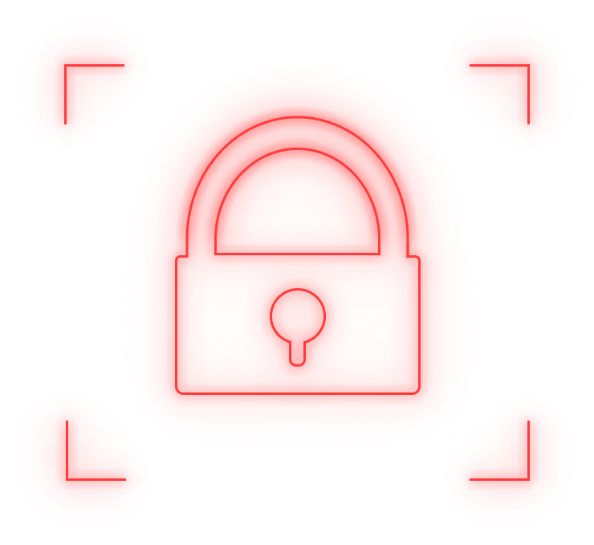
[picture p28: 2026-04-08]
Code/Codes_RaspPi/Qt/Interface_9avril/OverClockUI/OverClock/OverClockContent/images/CadenasRouge.png

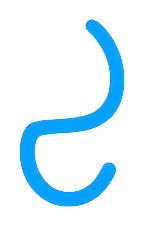
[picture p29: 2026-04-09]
Code/Codes_RaspPi/Qt/Interface_9avril/OverClockUI/OverClock/OverClockContent/images/genredeS_code.png

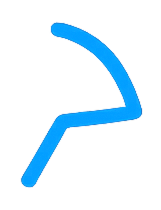
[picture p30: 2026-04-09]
Code/Codes_RaspPi/Qt/Interface_9avril/OverClockUI/OverClock/OverClockContent/images/interogtion_code.png

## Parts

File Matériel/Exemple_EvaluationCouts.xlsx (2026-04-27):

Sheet: Liste
Commande de composants électroniques | Description | Lien Web chez le fournisseur | Prix unitaire | Quantité | Transport | Total
Raspberry Pi | Raspberry Pi 4 Model B/4GB | https://www.pishop.ca/product/raspberry-pi-4-model-b-4gb/?searchid=0&search_query=Pi+4%60 | 139.95 $ | 1 | 11.83 $ | 151.78 $
ESP32-C3-DevKitC-02U | WiFi Development Tools - 802.11 ESP32-C3 general-purpose development board, embeds ESP32-C3-WROOM-02U-N4, 4 MB flash, with pin header | https://www.mouser.ca/ProductDetail/Espressif-Systems/ESP32-C3-DevKitC-02U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 | 12.00 $ | 3 | 0.00 $ | 36.00 $
1500 Protector Case | Mallete Pelican modèle 1500 | https://www.pelican.com/ca/en/product/cases/1500?sku=1500-001-110 | 232.95 $ | 1 | 0.00 $ | 232.95 $
0.1inch HDMI LCD (B) (with case) | 10.1inch Capacitive Touch Screen LCD (B) with Case, 1280×800, HDMI, IPS Screen, Low Power | https://www.waveshare.com/10.1inch-hdmi-lcd-b-with-case.htm | 110.99 $ | 1 | 38.00 $ | 148.99 $
PCBs | Cartes électronique pour le projet. Comprends la carte principale et celle pour les RFID | https://jlcpcb.com/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 | 8.12 $ | 1 | 50.00 $ | 58.12 $
Commande de composants électroniques | Digikey + Mouser | Commande | 237.16 $ | 1 |  | 237.16 $
 |  |  |  |  |  | 0.00 $
 |  |  |  |  |  | 0.00 $
 |  |  |  |  |  | 0.00 $
 |  |  |  |  |  | 0.00 $
 |  |  |  |  |  | 0.00 $
 |  |  |  |  |  | 0.00 $
 |  |  |  |  |  | 0.00 $
 |  |  |  |  |  | 0.00 $
 |  |  | Sous-total |  |  | 865.00 $
 |  |  | Taxes |  |  | 129.75 $
 |  |  | Grand Total |  |  | 994.75 $

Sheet: Commande
Commande de composants
Description | Prix unitaire | Quantité | Total item | Fournisseur | # Modèle pour commande | Hyperlien pour commande (si disponible) ou soumission | Prix hors taxe | taxe | Livraison | Total
CAP CER 0.1UF 16V X7R 0805, CAP CER 0.1UF 25V X7R 0805 | 0.18 $ | 10 | 1.80 $ | mouser.ca | 80-C0805C104M4R | https://www.mouser.ca/ProductDetail/KEMET/C0805C104M4RACTU?qs=VOOUd%252Bza08rn8%252BKVjcWMVQ%3D%3D | 184.27 $ | 12.90 $ | 40.00 $ | 237.16 $
Single Color LEDs SMD 0805 GREEN 560nm | 0.75 $ | 7 | 5.25 $ | mouser.ca | 645-5975316507F | https://www.mouser.ca/ProductDetail/Dialight/5975316507F?qs=gTYE2QTfZfT42%252BCs2jfhAg%3D%3D
Fuse Holder T/H 2 IN 1 AUTO BLDE HOLDER, YELLOW 20A | 1.97 $ | 5 | 9.85 $ | mouser.ca | 534-3557-20 | https://www.mouser.ca/ProductDetail/Keystone-Electronics/3557-20?qs=iR2ablhfrmF%2FWhSZXEYN7g%3D%3D
Fuse Holder T/H 2 IN 1 AUTO BLDE HOLDER, RED 10A | 2.03 $ | 5 | 10.15 $ | mouser.ca | 534-3557-10 | https://www.mouser.ca/ProductDetail/Keystone-Electronics/3557-10?qs=iR2ablhfrmF7t%2F4oUDx%252B%2Fw%3D%3D
Headers & Wire Housings 24 CRT VERT HEADER | 5.27 $ | 3 | 15.81 $ | mouser.ca | 538-39-29-9243 | https://www.mouser.ca/ProductDetail/Molex/39-29-9243?qs=DQ3LI50eFWbK%252BUDchTyndA%3D%3D
Headers & Wire Housings .100 Shrouded Terminal Strip | 5.69 $ | 3 | 17.07 $ | mouser.ca | 200-TSS12001TD | https://www.mouser.ca/ProductDetail/Samtec/TSS-120-01-T-D?qs=rU5fayqh%252BE0fe8yiSPJ69Q%3D%3D
Headers & Wire Housings Micro-Fit+ RA Header 3 Circuits Black | 3.28 $ | 10 | 32.80 $ | mouser.ca | 538-216571-1003 | https://www.mouser.ca/ProductDetail/Molex/216571-1003?qs=aP1CjGhiNiG31dsw841K9g%3D%3D
Headers & Wire Housings VERT HDR SMC 3P without board lock | 2.89 $ | 5 | 14.45 $ | mouser.ca | 538-43160-0103 | https://www.mouser.ca/ProductDetail/Molex/43160-0103?qs=P7cO%252B%252BFDLzTsTkAe5N5p%252Bg%3D%3D
Interface - I/O Expanders 16bit Input/Output Exp SPI interface | 2.59 $ | 3 | 7.77 $ | mouser.ca | 579-MCP23S17-E/SO | https://www.mouser.ca/ProductDetail/Microchip-Technology/MCP23S17-E-SO?qs=usxtMOJb1RzJScThsWtScg%3D%3D
B2B-PH-K-S | 0.15 $ | 20 | 3.00 $ | mouser.ca | 306-B2BPHKSLFSNPP | https://www.mouser.ca/ProductDetail/JST-Commercial/B2B-PH-K-SLFSN?qs=cdbOS8ANM9AlozzPlOt72g%3D%3D
Thick Film Resistors - SMD 0603 4K7ohm 5% Anti Surge AEC-Q200 | 0.22 $ | 24 | 5.28 $ | mouser.ca | 755-ESR03EZPJ472 | https://www.mouser.ca/ProductDetail/ROHM-Semiconductor/ESR03EZPJ472?qs=DyUWGjl%252BcVtkRvvrQHOTyA%3D%3D
Thick Film Resistors - SMD 0805 Anti-Surge Res. 0.1%, 330ohm | 0.32 $ | 12 | 3.84 $ | mouser.ca | 667-ERJ-PB6B3300V | https://www.mouser.ca/ProductDetail/Panasonic/ERJ-PB6B3300V?qs=eFOtW6xYNWFhIWygg2og3A%3D%3D
Thin Film Resistors - SMD 1KOhms 0805 0.25W 100ppm 1% Hi Pwr Anti-Sulfur | 0.15 $ | 5 | 0.75 $ | mouser.ca | 708-RNCP0805FTD1K00 | https://www.mouser.ca/ProductDetail/SEI-Stackpole/RNCP0805FTD1K00?qs=FESYatJ8odKy9z1hnQn%252Bhg%3D%3D
Thick Film Resistors - SMD 0805 Anti-Surge Res. 0.1%, 4.7Kohm | 0.32 $ | 3 | 0.96 $ | mouser.ca | 667-ERJ-PB6B4701V | https://www.mouser.ca/ProductDetail/Panasonic/ERJ-PB6B4701V?qs=eFOtW6xYNWEHNAylU4xJeQ%3D%3D
SLW-1711575-5A-N-D | 0.61 $ | 3 | 1.83 $ | mouser.ca | 179-SLW17115755AND | https://www.mouser.ca/ProductDetail/Same-Sky/SLW-1711575-5A-N-D?qs=IKkN%2F947nfCI%2FYNFg6qyCw%3D%3D
Bus Transceivers Tri-State Octal Bus A 595-SN74AHCT245PW A 595-SN74AHCT245PW | 1.04 $ | 3 | 3.12 $ | mouser.ca | 595-SN74AHCT245PWR | https://www.mouser.ca/ProductDetail/Texas-Instruments/SN74AHCT245PWR?qs=vxEfx8VrU7DerZZBYgV7Yw%3D%3D
CONN MOD JACK 8P8C R/A SHIELDED | 1.19 $ | 12 | 14.26 $ | DigiKey | AE10387-ND | https://www.digikey.ca/en/products/detail/assmann-wsw-components/A-2004-2-4-LPS-N-R/2183638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
CONN RCPT USB2.0 TYPEA 4POS R/A | 0.97 $ | 3 | 2.91 $ | DigiKey | 609-1045-ND | https://www.digikey.ca/en/products/detail/amphenol-cs-fci/87520-0010BLF/1001359
CONN HEADER VERT 8POS 2.54MM | 0.49 $ | 6 | 2.94 $ | DigiKey | WM4206-ND | https://www.digikey.ca/en/products/detail/molex/0022232081/26679?s=N4IgTCBcDaIOoFkAsYAMA2AtAOQCIgF0BfIA
RES SMD 330 OHM 0.1% 1/4W 0805 | 0.21 $ | 3 | 0.63 $ | Digikey | P20537CT-ND | https://www.digikey.ca/en/products/detail/panasonic-industry/ERJ-PB6B3300V/6213320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
CAP ALUM 330UF 20% 16V SMD | 0.71 $ | 10 | 7.10 $ | Digikey | 732-8525-1-ND | https://www.digikey.ca/en/products/detail/w%C3%BCrth-elektronik/865060353008/5728120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
CONN HEADER VERT 4POS 2MM | 0.16 $ | 6 | 0.96 $ | Digikey | 455-1706-ND | https://www.digikey.ca/en/products/detail/jst-sales-america-inc/B4B-PH-K-S/926613
FUSE AUTO 2A 32VDC BLADE ATO/ATC | 0.60 $ | 3 | 1.80 $ | Digikey | 0287002.H-ND | https://www.digikey.ca/en/products/detail/littelfuse-inc/0287002-H/3104041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
FUSE AUTO 10A 32VDC BLADE ATO | 0.60 $ | 3 | 1.80 $ | Digikey | F11064-ND | https://www.digikey.ca/en/products/detail/littelfuse-inc/0287010-H/3104045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
FUSE AUTO 20A 32VDC BLADE ATO | 0.60 $ | 3 | 1.80 $ | Digikey | F11066-ND | https://www.digikey.ca/en/products/detail/littelfuse-inc/0287020-H/3104047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
CONN RCPT HSG 3POS 3.00MM | 0.46 $ | 10 | 4.64 $ | Digikey | 900-2157591003-ND | https://www.digikey.ca/en/products/detail/molex/2157591003/14668554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
MICRO-FIT PLUS FEMCRPTER 20-24AW | 0.13 $ | 50 | 6.29 $ | Digikey | WM26579CT-ND | https://www.digikey.ca/en/products/detail/molex/2064600021/10209736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
CONN HSG RCPT 3POS 7.50MM BLACK | 0.78 $ | 2 | 1.56 $ | Digikey | WM18464-ND | https://www.digikey.ca/en/products/detail/molex/0444412003/300097?s=N4IgTCBcDaIOoFkCMAOALANjQWgHIBEQBdAXyA
TERM BLADE FEMALE 14-16AWG TIN | 0.09 $ | 10 | 0.90 $ | Digikey | WM9174CT-ND | https://www.digikey.ca/en/products/detail/molex/0433750001/592656?s=N4IgTCBcDaIOoFkCcBGA7AFgMIBUC0AcgCIgC6AvkA
GPIO RIBBON CABLE FOR RASPBERRY | 2.95 $ | 1 | 2.95 $ | Digikey | 1528-2235-ND | https://www.digikey.ca/en/products/detail/adafruit-industries-llc/1988/7241480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

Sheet: Infos
Les cellules en bleues doivent se calculer automatiquement (utiliser une formule).
Dans l'évaluation des coûts, ne pas oublier:
Les cartes de développements
Les PCB (prévoir 50$ comme frais de livraisons)
Les connecteurs
Les câbles ou fils si longues distances
Les boîtiers
Ne pas mettre les composants discrets (résistances, condensateurs, etc) de moins de $2.00

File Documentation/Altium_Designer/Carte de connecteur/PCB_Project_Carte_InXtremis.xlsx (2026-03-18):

Comment | Description | Designator | Footprint | LibRef | Quantity
330 µF | CAP ALUM 330UF 20% 16V SMD | C1, C3, C4, C5 | CAP ALSMD 8.3MM H10.5MM | 865060353008 | 4
0.1 µF | CAP CER 0.1UF 25V X7R 0805 | C2, C6 | CAP 0805_2012 | 0805Y0250104KXT | 2
Green | LED GREEN 0805 SMD | D1, D2, D3 | LED 0805_2012 GREEN | 5975316507F | 3
3557-10 |  | F1, F2, F3 | FUSE_3557-10 | 3557-10 | 3
39299243 | Conn Wire to Board HDR 24Power POS 4.2mm Solder ST Top Entry Thru-Hole Tray | J1 | MOLEX_39299243 | 39299243 | 1
TSS-120-01-T-D | Connector Header Through Hole 40 position 0.100 (2.54mm) | J2 | SAMTEC_TSS-120-01-T-D | TSS-120-01-T-D | 1
2165711003 | Micro-Fit+ Vertical Header, Through Hole, 3.00mm Pitch, Single Row, 3 Circuits, Matte Tin (Sn) Plating, Glow-Wire Capable, Black | J3, J4, J5, J6, J7, J8, J9 | CONN_2165710003-SD_03_MOL | 2165711003 | 7
431600103 | Sabre Vertical Header, 3 Circuits, Glow-Wire Capable, PCB Thickness 1.60mm, without Board Lock | J10 | CONN_431600001-SD_V_03_MOL | 431600103 | 1
A-2004-2-4-LPS-N-R | CONN MOD JACK 8P8C R/A SHIELDED | J11, J12, J13, J20 | ASSMANN A-2004-2-4-LPS-N-R | A-2004-2-4-LPS-N-R | 4
B4B-PH-K-S |  | J14, J30 | JST_B4B-PH-K-S | B4B-PH-K-S | 2
MCP23S17-E/SO | Microchip MCP23S17-E/SO,16-channel 16bit I/O Exp&er 5MHz,Serial-SPI,28-Pin SOIC | Microchip Technology Inc. MCP23S17-E/SO | J15 | SOIC127P1030X265-28N | MCP23S17-E/SO | 1
B2B-PH-K-S | Connector Header Through Hole 2 position 0.079 (2.00mm) | J16, J17, J18, J19, J21, J22, J23, J24, J25, J26, J27, J28, J29, J31 | JST_B2B-PH-K-S | B2B-PH-K-S | 14
87520-0010BLF | Conn Data USB TypeA Socket 4Cnts RightAngle ThruHole White 1.57mmPCB | Amphenol FCI (Amphenol CS) 87520-0010BLF | J32 | AMPHENOL_87520-0010BLF | 87520-0010BLF | 1
2165711002 |  | J33 | MOLEX_2165711002 | 2165711002 | 1
4.7 kOhms | RES SMD 4.7K OHM 5% 1/4W 0603 | R1, R2, R3, R4, R5, R6, R7, R8, R9, R10, R11, R12, R13, R14, R15, R16, R17, R18 | RES 0603_1608 | ESR03EZPJ472 | 18
330 Ohms | RES SMD 330 OHM 0.1% 1/4W 0805 | R19, R20, R21, R24, R25, R26, R27, R28 | RES 0805_2012 | ERJ-PB6B3300V | 8
1 kOhms | RES 1K OHM 1% 1/4W 0805 | R22 | RES 0805_2012 | RNCP0805FTD1K00 | 1
4.7 kOhms | RES SMD 4.7K OHM 0.1% 1/4W 0805 | R23 | RES 0805_2012 | ERJ-PB6B4701V | 1
SLW-1711575-5A-N-D | Switch Slide ON ON SPDT Raised Slide 0.3A 50VDC 10000Cycles PC Pins Thru-Hole | S1 | SW_SLW-1711575-5A-N-D | SLW-1711575-5A-N-D | 1
ESP32-C3-DEVKITC-02 | The ESP32-C3-DEVKITC-02 Evaluation Board from Espressif Systems is a development platform for wireless applications, offering 802.11 b/g/n Wi-Fi and Bluetooth (BLE) connectivity at 2.4GHz. Powered by the ESP32-C3-WROOM-02 module, it features a 32-bit RISC | U2, U4, U5 | XCVR_ESP32-C3-DEVKITC-02 | ESP32-C3-DEVKITC-02 | 3
SN74AHCT245PWR |  | U3 | SOP65P640X120-20N | SN74AHCT245PWR | 1

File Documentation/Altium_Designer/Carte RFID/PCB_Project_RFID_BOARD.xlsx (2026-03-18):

Comment | Description | Designator | Footprint | LibRef | Quantity
0.1 µF | CAP CER 0.1UF 25V X7R 0805 | C1 | CAP 0805_2012 | 0805J0250104KXT | 1
Green | LED GREEN 0805 SMD | D1 | LED 0805_2012 GREEN | 5975316507F | 1
A-2004-2-4-LPS-N-R | CONN MOD JACK 8P8C R/A SHIELDED | J1, J2 | ASSMANN A-2004-2-4-LPS-N-R | A-2004-2-4-LPS-N-R | 2
22232081 |  | J3, J4, J5, J6 | CONN_A-6373-08A_MOL | 22232081 | 4
330 Ohms | RES SMD 330 OHM 0.1% 1/4W 0805 | R1 | RES 0805_2012 | ERJ-PB6B3300V | 1

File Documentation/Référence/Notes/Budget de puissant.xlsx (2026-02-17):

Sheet: Budget de Puissance
Budget de puissance |  |  |  |  |  |  | Puissance total @12V (W) |  | Courant total @12V (A)
Composant | Qté | Tension (V) | Courant unitaire (A) | Courant total (A) | Puissance (w) | Notes | 145.62 |  | 12.135
Raspberry Pi 4 | 1 | 5 | 3 | 3 | 15 | 3A peak | Puissance total @5V (W) |  | Courant total @5V (A)
ESP32-C3 | 3 | 5 | 0.1 | 0.3 | 1.5 | ESP32 consommation max | 85.62 |  | 17.124
 |  |  |  |  |  |  |  | 91.08510638
7 Del | 7 | 5
Matrice de 256 | 256 | 5 | 0.054 | 13.824 | 69.12 | puissance max en blanc |  | 5.465106383
5 Strip Del 40 Del | 5 | 12 | 0.025 | 5 | 60
 |  |  |  | 0 |  |  |  | 1.821702128
 |  |  |  | 0
 |  |  |  | 0
 |  |  |  | 0
 |  |  |  | 0 |  |  |  | 263.8251489

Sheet: Calcul thermique
Calcul thermique

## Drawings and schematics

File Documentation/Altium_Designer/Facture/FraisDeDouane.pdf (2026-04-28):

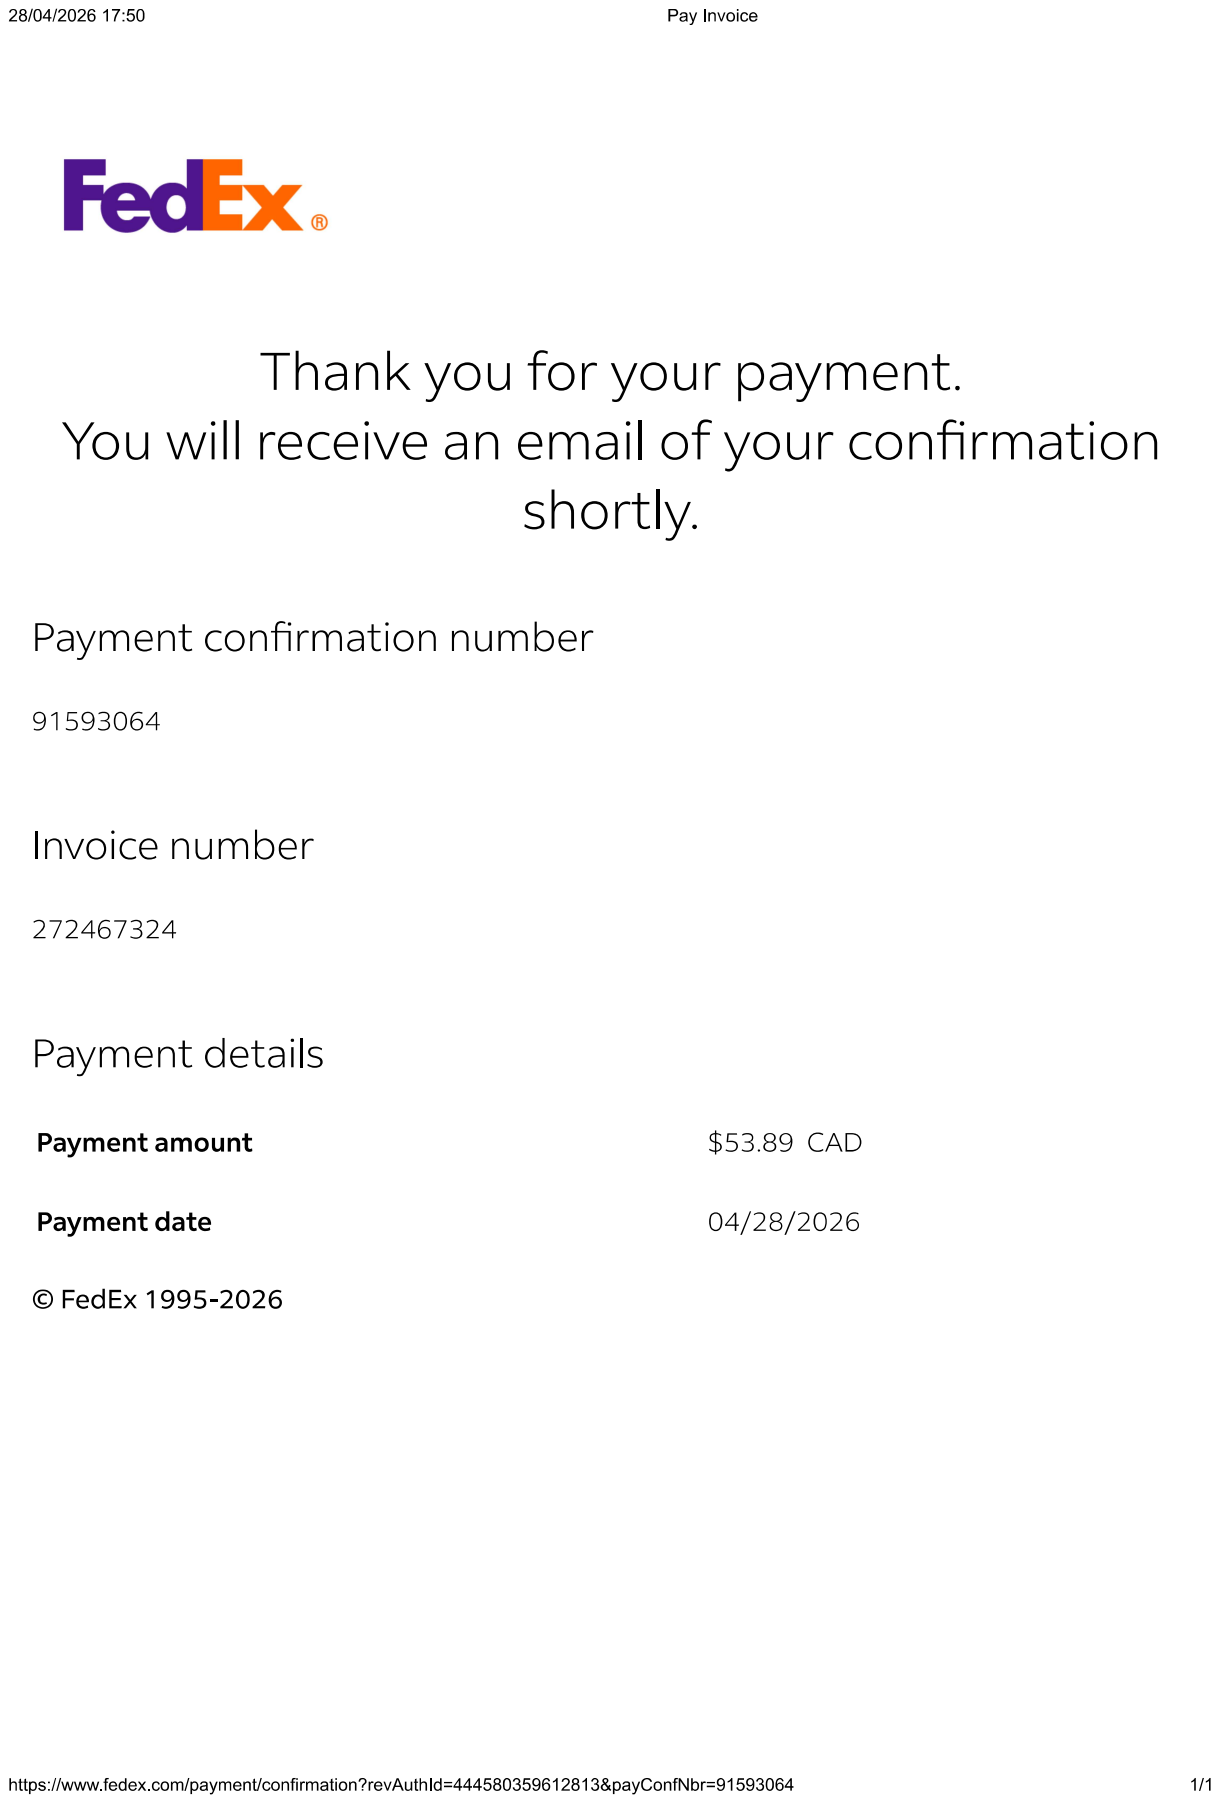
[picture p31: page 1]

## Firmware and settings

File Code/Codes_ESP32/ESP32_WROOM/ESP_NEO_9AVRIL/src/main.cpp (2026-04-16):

#include <Arduino.h>
#include <FastLED.h> //Bibliothèque pour la gestion des LEDs
#include <Wire.h> //Communication I2C entre les esp32 et le PI
#include <string.h> //Pour la manipulation des string
#include <ArduinoJson.h>

#define SLAVE_ADDR 0x12  // Adresse de l'esclave

#define SDA_PIN 6
#define SCL_PIN 7

#define DATA_PIN_E1_0     9   // Pin de données pour la bande de LEDs
#define DATA_PIN_E1_1     10  // Pin de données pour la bande de LEDs
#define DATA_PIN_E1_2     5  // Pin de données pour la bande de LEDs
#define DATA_PIN_E1_3     4  // Pin de données pour la bande de LEDs
#define DATA_PIN_E1_4     3  // Pin de données pour la bande de LEDs
#define DATA_PIN_E2       0  // Pin de données pour la bande de LEDs

#define NB_STRIP 6      // Nombre de bandes de LEDs
#define NB_LEDS_STRIP_E1_0 60 // Nombre de LEDs sur la bande 1
#define NB_LEDS_STRIP_E1_1 60 // Nombre de LEDs sur la bande 2
#define NB_LEDS_STRIP_E1_2 60 // Nombre de LEDs sur la bande 3
#define NB_LEDS_STRIP_E1_3 60 // Nombre de LEDs sur la bande 4
#define NB_LEDS_STRIP_E1_4 60 // Nombre de LEDs sur la bande 5
#define NB_LEDS_STRIP_E2 17 // Nombre de LEDs sur la bande 6

String g_stringOfAllData = "";
int g_compteur = 0; // Compteur pour flasher la strip sélectionnée
int g_stripSelected = -1; // -1 signifie qu'aucune strip n'est sélectionnée, sinon 0 à 4 pour les strips E2_0 à E2_4
int g_couleurStripSelected[3] = {0, 0, 0}; // Couleur de la strip sélectionnée (R, G, B)
int g_animationIndex = -1; // -1 signifie aucune animation, sinon 0 à 11 pour les différentes étapes de l'énigme 2

CRGB ledsE1_0[NB_LEDS_STRIP_E1_0];
CRGB ledsE1_1[NB_LEDS_STRIP_E1_1];
CRGB ledsE1_2[NB_LEDS_STRIP_E1_2];
CRGB ledsE1_3[NB_LEDS_STRIP_E1_3];
CRGB ledsE1_4[NB_LEDS_STRIP_E1_4];
CRGB* tableauDeStrips[NB_STRIP - 1] = {
  ledsE1_0,
  ledsE1_1,
  ledsE1_2,
  ledsE1_3,
  ledsE1_4
};

const int tableauDeNbLeds[NB_STRIP - 1] = {
  NB_LEDS_STRIP_E1_0,
  NB_LEDS_STRIP_E1_1,
  NB_LEDS_STRIP_E1_2,
  NB_LEDS_STRIP_E1_3,
  NB_LEDS_STRIP_E1_4
};

CRGB ledsE2[NB_LEDS_STRIP_E2];

// put function declarations here:
void requestData(); //Prototype de fonction
void commandeI2C(int howMany);
void decodeJSON(JsonDocument& doc);
void fill_Enigme2(CRGB color);

void setup() 
{
  // Initialisation du port série pour le debug 
  Serial.begin(9600);

  // Initialisation de l'I2C en tant qu'esclave avec l'adresse définie 
  Wire.setPins(SDA_PIN, SCL_PIN);
  Wire.begin(SLAVE_ADDR);

  FastLED.addLeds<WS2812, DATA_PIN_E1_0, GRB>(ledsE1_0, NB_LEDS_STRIP_E1_0);
  FastLED.addLeds<WS2812, DATA_PIN_E1_1, GRB>(ledsE1_1, NB_LEDS_STRIP_E1_1);
  FastLED.addLeds<WS2812, DATA_PIN_E1_2, GRB>(ledsE1_2, NB_LEDS_STRIP_E1_2);
  FastLED.addLeds<WS2812, DATA_PIN_E1_3, GRB>(ledsE1_3, NB_LEDS_STRIP_E1_3);
  FastLED.addLeds<WS2812, DATA_PIN_E1_4, GRB>(ledsE1_4, NB_LEDS_STRIP_E1_4);
  FastLED.addLeds<WS2812, DATA_PIN_E2, GRB>(ledsE2, NB_LEDS_STRIP_E2);

  FastLED.setBrightness(255); // Régle la luminosité des LEDs à 255 (maximum)
  FastLED.clear(); // Efface les LEDs (les éteint)
  FastLED.show(); // Affiche les LEDs (initialement éteintes)

  // Attacher une fonction de demande (request) pour le maître 
  Wire.onReceive(commandeI2C);

  Serial.println("Slave prêt, en attente de requêtes du maître..."); 
}

void loop() 
{
  if (g_stripSelected != -1) 
  {
    // Faire clignoter la strip sélectionnée pour indiquer qu'elle est sélectionnée
    if (g_compteur <= 5 ) 
    { // Clignote toutes les 10 itérations (environ toutes les 500 ms)
      fill_solid(tableauDeStrips[g_stripSelected], tableauDeNbLeds[g_stripSelected], CRGB(g_couleurStripSelected[0], g_couleurStripSelected[1], g_couleurStripSelected[2])); // Allumer la strip sélectionnée avec la couleur spécifiée
    } 
    else if (g_compteur <= 7)
    {
      fill_solid(tableauDeStrips[g_stripSelected], tableauDeNbLeds[g_stripSelected], CRGB::Black); // Éteindre la strip sélectionnée
    }
    else
    {
      g_compteur = 0; // Réinitialiser le compteur pour recommencer le clignotement
    }
    FastLED.show();
  }
  
  switch (g_animationIndex)
  {
    case 0: // Tout en rouge
      fill_Enigme2(CRGB::Red); // Allumer les LEDs paires en rouge
      FastLED.show();

      break;

    case 1: // Animation échec
      for (int i = 0; i < 5; i++)
      {
        fill_Enigme2(CRGB::Red); // Allumer les LEDs paires en rouge
        FastLED.show();
        delay(500); // Attendre 500 millisecondes

        fill_Enigme2(CRGB::Black); // Éteindre les LEDs paires
        FastLED.show();
        delay(500); // Attendre 500 millisecondes
      }

      fill_Enigme2(CRGB::Red); // Allumer les LEDs paires en rouge
      FastLED.show();

      g_animationIndex = -1; // Réinitialiser l'index de l'animation pour éviter de répéter l'animation

      break;

    case 2: // Animation réussite
      for (int i = 0; i < 5; i++)
      {
        fill_Enigme2(CRGB::Green); // Allumer les LEDs paires en vert
        FastLED.show();
        delay(500); // Attendre 500 millisecondes

        fill_Enigme2(CRGB::Black); // Éteindre les LEDs paires
        FastLED.show();
        delay(500); // Attendre 500 millisecondes
      }
      
      fill_Enigme2(CRGB::Green); // Allumer les LEDs paires en vert
      FastLED.show();

      g_animationIndex = -1; // Réinitialiser l'index de l'animation pour éviter de répéter l'animation
      
      break;

    case 3: // 1ère DEL en vert
      ledsE2[0] = CRGB::Green; // Allumer la première colonne de LEDs en vert
      FastLED.show();

      break;

    case 4: // 2ème DEL en vert
      ledsE2[2] = CRGB::Green; // Allumer la première colonne de LEDs en vert
      FastLED.show();

      break;

    case 5: // 3ème DEL en vert
      ledsE2[4] = CRGB::Green; // Allumer la première colonne de LEDs en vert
      FastLED.show();

      break;

    case 6: // 4ème DEL en vert
      ledsE2[6] = CRGB::Green; // Allumer la première colonne de LEDs en vert
      FastLED.show();

      break;

    case 7: // 5ème DEL en vert
      ledsE2[8] = CRGB::Green; // Allumer la neuvième colonne de LEDs en vert
      FastLED.show();

      break;

    case 8: // 6ème DEL en vert
      ledsE2[10] = CRGB::Green; // Allumer la onzième colonne de LEDs en vert
      FastLED.show();

      break;

    case 9: // 7ème DEL en vert
      ledsE2[12] = CRGB::Green; // Allumer la treizième colonne de LEDs en vert
      FastLED.show();

      break;

    case 10: // 8ème DEL en vert
      ledsE2[14] = CRGB::Green; // Allumer la quinzième colonne de LEDs en vert
      FastLED.show();

      break;

    case 11: // 9ème DEL en vert
      ledsE2[16] = CRGB::Green; // Allumer la dix-septième colonne de LEDs en vert
      FastLED.show();
      break;
      
    case 12: // Éteindre toutes les DELs
      fill_Enigme2(CRGB::Black); // Éteindre les LEDs paires
      FastLED.show();
      break;

    default:
      break;
  }

  g_animationIndex = -1; // Réinitialiser l'index de l'animation pour éviter de répéter l'animation
  g_compteur++; // Incrémenter le compteur pour faire clignoter la strip sélectionnée
  delay(100); // Petite pause pour éviter de surcharger le processeur
}

// put function definitions here:
/*
Brief : Fonction appelée lorsque le maître envoie une commande
*/
void commandeI2C(int howMany) {
  // Lire les données envoyées par le maître
  g_stringOfAllData = "";
  while (Wire.available()) {
    char c = Wire.read();
    g_stringOfAllData += c;
  }
  Serial.println("Données reçues du maître: " + g_stringOfAllData);

  // Parsing du JSON
  JsonDocument doc;
  DeserializationError error = deserializeJson(doc, g_stringOfAllData);

  if (error) {
    Serial.print("Erreur JSON: ");
    Serial.println(error.c_str());
    return;
  }

  decodeJSON(doc);
}

/*
Format du JSON attendu : 
Énigme 1 : {"E":1,"Selected":0,"S0":"#FF0000","S1":"#00FF00","S2":"#0000FF","S3":"#FFFF00","S4":"#00FFFF"}
   - E : numéro de l'énigme (pour vérification)
   - Selected : numéro du strip sélectionné (0 à 4) ou -1 si aucun strip n'est sélectionné
     - Si Selected est différent de -1, alors la strip doit flasher pour indiquer qu'elle est sélectionnée
   - S0 à S4 : couleurs au format hexadécimal pour chaque strip
   Exemple : {"E":1,"Selected":0,"S0":"#FF0000","S1":"#00FF00","S2":"#0000FF","S3":"#FFFF00","S4":"#00FFFF"}
   Ce format permet de transmettre toutes les informations nécessaires pour mettre à jour les couleurs des strips en une seule commande JSON.
Énigme 2 : {"E":NUM_ENIGME,"Etape":MSG}
    - E : numéro de l'énigme (pour vérification)
    - Etape : Étape de del
      - 0 toutes la strip en rouge
      - 1 erreur, la strip doit flasher en rouge 5 fois 500 ms on et 500 ms off
      - 2 succès, la strip doit flasher en vert 5 fois 500 ms on et 500 ms off
      - 3 1er del en vert et les autres en rouge
      - 4 2 premières del en vert et les autres en rouge
      - 5 3 premières del en vert et les autres en rouge
      - 6 4 premières del en vert et les autres en rouge
      - 7 5 premières del en vert et les autres en rouge
      - 8 6 premières del en vert et les autres en rouge
      - 9 7 premières del en vert et les autres en rouge
      - 10 8 premières del en vert et les autres en rouge
      - 11 9 premières del en vert et les autres en rouge
*/
void decodeJSON(JsonDocument& doc) {
  int enigme = doc["E"];
  if (enigme == 1) {
    g_stripSelected = doc["Selected"];
    g_compteur = 0; // Réinitialiser le compteur pour faire clignoter la strip sélectionnée
    for (int i = 0; i < NB_STRIP - 1; i++) {
      String colorStr = doc["S" + String(i)].as<String>();
      long colorLong = strtol(colorStr.substring(1).c_str(), NULL, 16);
      CRGB color = CRGB((colorLong >> 16) & 0xFF, (colorLong >> 8) & 0xFF, colorLong & 0xFF);
      if (i == g_stripSelected) {
        g_couleurStripSelected[0] = color.r;
        g_couleurStripSelected[1] = color.g;
        g_couleurStripSelected[2] = color.b;
      }
      switch (i) {
        case 0: fill_solid(ledsE1_0, NB_LEDS_STRIP_E1_0, color); break;
        case 1: fill_solid(ledsE1_1, NB_LEDS_STRIP_E1_1, color); break;
        case 2: fill_solid(ledsE1_2, NB_LEDS_STRIP_E1_2, color); break;
        case 3: fill_solid(ledsE1_3, NB_LEDS_STRIP_E1_3, color); break;
        case 4: fill_solid(ledsE1_4, NB_LEDS_STRIP_E1_4, color); break;
      }
    }
    FastLED.show();
  } 
  else if (enigme == 2) {
    g_animationIndex = doc["Etape"];
  } 
  else {
    Serial.println("Numéro d'énigme inconnu: " + String(enigme));
  }
}

void fill_Enigme2(CRGB color) {
  for (int i = 0; i < NB_LEDS_STRIP_E2; i++) {
    if (i % 2 == 0) {
      ledsE2[i] = color; // Allumer les LEDs paires avec la couleur spécifiée
    }
  }
  FastLED.show();
}

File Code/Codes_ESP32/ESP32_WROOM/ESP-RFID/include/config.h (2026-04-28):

/**
 * @file config.h
 * @brief Fichier de configuration des broches et paramètres pour la gestion des lecteurs RFID MFRC522 avec ESP32 en tant qu'esclave I2C.
 * @author Adam Dubois
 * @date 2026-02-05
 * @version 1.0
 * 
 * Ce fichier définit les broches utilisées pour la communication I2C et SPI, 
 * ainsi que les paramètres spécifiques aux lecteurs RFID MFRC522.
 * Si vous voulez modifier le nombre de lecteurs ou les broches utilisées, c'est ici que ça se passe.
 */

#ifndef CONFIG_H
#define CONFIG_H



// ============================================================================================================
// Includes
// ============================================================================================================

// L'ordre des includes est important, les includes qui en utilisent d'autres doivent être inclus après ceux-ci. Par exemple, Debug_Neo.h doit être inclus après config.h et Adafruit_NeoPixel.h, car il utilise les paramètres définis dans config.h et la bibliothèque Adafruit_NeoPixel.
#include <Arduino.h>
#include <string.h> //Pour la manipulation des strings
#include <Wire.h> //Communication I2C entre les esp32 et le PI
#include <SPI.h> //Bibliothèque SPI pour la communication avec le MFRC522
#include <MFRC522.h> //Bibliothèque MFRC522 pour la gestion du lecteur RFID
#include <Adafruit_NeoPixel.h> //Bibliothèque pour la gestion du NeoPixel
#include "Debug_Neo.h" // Classe pour gérer les différentes couleurs du NeoPixel en fonction de l'état du système



// ============================================================================================================
// Définitions des constantes et paramètres
// ============================================================================================================

// --------------------------------
// Débogage série
// --------------------------------
// Si le mode de débogage est activé, les logs seront affichés dans le moniteur série.
// Pour activer ou désactiver le mode de débogage, il suffit de changer la valeur de DEBUG_MODE à true ou false.
// La macro debug(...) peut aussi être modifiée pour afficher ce qu'on veut dans le terminal série.
#define DEBUG_MODE false // Mettre à true pour activer les logs série, false pour désactiver

#if DEBUG_MODE == true // Si le mode débogage est activé on définit les macros debug
    #define debug(...) printf("[DEBUG] : " __VA_ARGS__)
#else
    #define debug(...) // Si le mode de débogage est désactivé, la macro debug ne fait rien
#endif

// --------------------------------
// Nom de l'ESP32 esclave
// --------------------------------
// Le nom de l'ESP32 esclave, qui sera envoyé au maître I2C dans la chaîne JSON.
// Peut être changé.
const String ESP32_NAME = "RFID";

// --------------------------------
// Néopixel de l'ESP32 esclave
// --------------------------------
// Les paramètres du NeoPixel (broche, nombre de LEDs, couleurs pour les différents états, etc.) sont définis ici.
// Le numéro de broche et le nombre de NeoPixels ne devrait pas être changé, il s'agit de la façon dont le ESP32-C3-WROOM-02 est câblé. 
// Cependant, les couleurs pour les différents états peuvent être changées en modifiant les valeurs de NEOPIXEL_COLOR_WAITING, NEOPIXEL_COLOR_WORKING, NEOPIXEL_COLOR_SUCCESS, NEOPIXEL_COLOR_ERROR et NEOPIXEL_COLOR_PROBLEM.
#define NEOPIXEL_PIN 8
#define NEOPIXEL_COUNT 1
#define NEOPIXEL_BRIGHTNESS 10 // Valeur de luminosité du NeoPixel (0-255)
#define NEOPIXEL_COLOR_WAITING strip.Color(0, 0, 255) // Bleu pour l'attente
#define NEOPIXEL_COLOR_WORKING strip.Color(255, 0, 255) // Mauve pour le travail
#define NEOPIXEL_COLOR_SUCCESS strip.Color(0, 255, 0) // Vert pour le succès
#define NEOPIXEL_COLOR_ERROR strip.Color(255, 0, 0) // Rouge pour l'erreur
#define NEOPIXEL_COLOR_PROBLEM strip.Color(255, 255, 0) // Jaune pour les problèmes

#if (NEOPIXEL_PIN != 8)
    #error "Le numéro de broche du NeoPixel doit être égal à 8, car il s'agit de la configuration matérielle de l'ESP32-C3-WROOM-02. Si vous utilisez un autre ESP32 ou une configuration différente, veuillez ajuster cette valeur et vérifier que les autres paramètres sont corrects."
#endif
#if (NEOPIXEL_COUNT != 1)
    #error "Le nombre de NeoPixels devrait être égal à 1, car il s'agit de la configuration matérielle de l'ESP32-C3-WROOM-02. Si vous utilisez un autre ESP32 ou une configuration différente, veuillez ajuster cette valeur et vérifier que les autres paramètres sont corrects."
#endif

// --------------------------------
// Configuration I2C
// --------------------------------
#define SLAVE_ADDR  0x11
#define SDA_PIN     6
#define SCL_PIN     7
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

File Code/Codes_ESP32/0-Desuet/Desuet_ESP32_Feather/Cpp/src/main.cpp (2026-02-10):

//-----------------------------------------------------------------//
// Includes
#include <Arduino.h>
#include <ArduinoJson.h>
#include <Wire.h> //Communication I2C entre les esp32 et le PI
#include <string.h> //Pour la manipulation des strings
#include <Adafruit_NeoPixel.h>
//#################################################################//

//-----------------------------------------------------------------//
//Constantes et définitions
#define Code "UART_Neo"

#define LED_PIN LED_BUILTIN // Pin de la LED intégrée

#define RX_PIN RX      // Exemple: GPIO17 = RX pour Serial1 ESP32
#define TX_PIN TX      // Exemple: GPIO18 = TX pour Serial1 ESP32

// Which pin on the ESP32 is connected to the NeoPixels? In this case, pin A5
#define NEO_LED_PIN A5

// How many NeoPixels are attached to the Arduino?
#define LED_COUNT 75

// Utilitaire safe sans dépendre de strip
#include <Adafruit_NeoPixel.h>
struct NamedColor {
  const char* name;
  uint32_t value;
};

const NamedColor color_table[] = {
  { "RED",    Adafruit_NeoPixel::Color(255, 0, 0) },
  { "GREEN",  Adafruit_NeoPixel::Color(0, 255, 0) },
  { "BLUE",   Adafruit_NeoPixel::Color(0, 0, 255) },
  { "YELLOW", Adafruit_NeoPixel::Color(255, 255, 0) },
  { "CYAN",   Adafruit_NeoPixel::Color(0, 255, 255) },
  { "MAGENTA",Adafruit_NeoPixel::Color(255, 0, 255) },
  { "WHITE",  Adafruit_NeoPixel::Color(255, 255, 255) },
  { "BLACK",  Adafruit_NeoPixel::Color(0, 0, 0) },
};

const int NB_COLORS = sizeof(color_table) / sizeof(color_table[0]);

#define ETAPES_BLINK 2 // Allumé et éteint
#define DELAY_BLINK 500 // Délai par défaut entre les étapes de l'animation Blink en ms
#define ETAPES_RAINBOW 256 // Nombre d'étapes pour l'animation Rainbow
#define DELAY_RAINBOW 0 // Délai par défaut entre les étapes de l'animation Rainbow en ms

//#################################################################//

//-----------------------------------------------------------------//
// Variables globales
String g_stringOfAllData = "";
bool g_News = false;

// Declare our NeoPixel strip object:
Adafruit_NeoPixel strip(LED_COUNT, NEO_LED_PIN, NEO_GRB + NEO_KHZ800);
// Argument 1 = Number of pixels in NeoPixel strip
// Argument 2 = Arduino pin number (most are valid)
// Argument 3 = Pixel type flags, add together as needed:
//   NEO_KHZ800  800 KHz bitstream (most NeoPixel products w/WS2812 LEDs)
//   NEO_KHZ400  400 KHz (classic 'v1' (not v2) FLORA pixels, WS2811 drivers)
//   NEO_GRB     Pixels are wired for GRB bitstream (most NeoPixel products)
//   NEO_RGB     Pixels are wired for RGB bitstream (v1 FLORA pixels, not v2)
//   NEO_RGBW    Pixels are wired for RGBW bitstream (NeoPixel RGBW products)

String g_stringCode = "";
String g_stringVerif = "";
String g_stringCmd = "";
String g_stringAnimation = "";
int g_intRepetition = 0;
int g_intNombre = 0;
int g_intDebut = 0;
String g_stringCouleur = "";
int g_intBrightness = 0;
int g_intDelai = -1;
int g_delayAnim = 0;
int g_repetitionAnim = 0;
int g_etapeAnim = 0;
int g_delayBetweenSteps = 0;
//#################################################################//

//-----------------------------------------------------------------//
// put function declarations here:
void initNeoPixels();
void testNeoPixels();
bool traitementMessageUART();
void commandeStat();
void commandeAnim();
uint32_t getColorByName(const String& nom);
void resetVariablesGlobals();
uint32_t rainbowColor(byte pos);
//#################################################################//

HardwareSerial SerialNeo(1);

void uartTask(void *param) {
  String buffer = "";
  while (1) {
    while (SerialNeo.available()) {
      char c = SerialNeo.read();
      if (c == '\n' || c == '\r') {
        //Serial.print("[UART Task] Message: ");
        //Serial.println(buffer);
        g_stringOfAllData = buffer;
        buffer = "";
        g_News = true; // Indique qu'il y a des nouvelles données
      } else {
        buffer += c;
      }
    }
    vTaskDelay(10 / portTICK_PERIOD_MS);
  }
}
//#################################################################//

//-----------------------------------------------------------------//
// the setup function runs once when you press reset or power the board
void setup() 
{
    // Initialisation du port série pour le debug 
    Serial.begin(115200);
    SerialNeo.begin(115200, SERIAL_8N1, RX_PIN, TX_PIN); // UART hardware pins
    xTaskCreatePinnedToCore(uartTask, "uartTask", 4096, NULL, 1, NULL, 1); // Lance sur le second CPU
    delay(3000); // Attendre un moment pour que le moniteur série soit prêt
    Serial.println("UART NeoPixel ESP32 Ready");

    // put your setup code here, to run once:
    // initialize digital pin LED_BUILTIN as an output.
    pinMode(LED_PIN, OUTPUT);

    initNeoPixels();
}
//#################################################################//

//-----------------------------------------------------------------//
// the loop function runs over and over again forever
void loop() 
{
    if (g_News) // S'il y a des nouvelles données à traiter
    {
        Serial.print("Données reçues dans loop: ");
        Serial.println(g_stringOfAllData);

        if(g_stringOfAllData == "") 
        {
            Serial.println("Aucune donnée reçue.");
        }
        else if(g_stringOfAllData == "TEST_NEO")
        {
            Serial.println("Lancement du test NeoPixels...");
            testNeoPixels();
            resetVariablesGlobals(); // Réinitialise les variables après exécution
        }
        else
        {
            Serial.println("Parsing du message JSON...");
            if(!traitementMessageUART())
            {
                Serial.println("Échec du traitement du message UART.");
                resetVariablesGlobals();
            }
        }
        g_News = false; // Réinitialise le drapeau
    }
    else
    {
        if (g_stringCmd == "Stat")
        {
            Serial.println("Commande Stat reçue.");
            commandeStat();
            resetVariablesGlobals(); // Réinitialise les variables après exécution
        }
        else if (g_stringCmd == "Anim")
        {
            if (g_etapeAnim == 0 && g_repetitionAnim == 0)
            {
                Serial.println("Commande Anim reçue.");
            }
            if (g_delayAnim <= 0)
            {
                commandeAnim();
                g_delayAnim = g_delayBetweenSteps; // Délai entre les étapes
            }
        }
    }

    delay(10); // Petite pause pour calculer les compteurs
    if (g_delayAnim >= 10)
    {
        g_delayAnim -= 10;
    }
    else 
    {
        g_delayAnim = 0;
    }
}
//#################################################################//
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

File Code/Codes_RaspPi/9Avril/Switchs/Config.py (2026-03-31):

#!/usr/bin/env python
#coding: utf-8
"""
Fichier : Config.py
Description: """
__author__ = "Adam Dubois"
__version__ = "1.0.1"
__date__ = ""
__maintainer__ = "Adam Dubois"
__email__ = "adamdubois19@hotmail.com"
__status__ = "Production"

#---------------------------------------------------------------------------------------------------------------------------------------#
#                                                                                                                                       #
# Configuration  de  l'énigme                                                                                                           #
#                                                                                                                                       #
#---------------------------------------------------------------------------------------------------------------------------------------#
# Si la switch est en NC (Not Connected), sa valeur est un True (1 logique), car la broche est tirée vers le haut (pull-up) et n'est pas connectée à la masse
# Si la switch est en CC (Connected), sa valeur est un False (0 logique), car la broche est connectée à la masse (GND)
# L'ordre des switchs peut changer, si elles sont connectées dans un ordre différent sur le MCP23S17 du ESP des IO.
# Voici les switchs et leur numéro d'index normalement actuel :
# Index 0 (SW0) : L'interrupteur à levier (NC quand il est en position Initiale et CC quand il est togglé)
# Index 1 (SW1) : Le boîtier avec les boutons "Start" et "Stop" (NC quand il est en position Initiale (Stop) et CC quand il est togglé (Start))
# Index 2 (SW2) : Le connecteur, branché/débranché (CC quand il est en position Initiale (branché) et NC quand il est débranché)
# Index 3 (SW3) : L'interrupteur à tourner (NC quand il est en position Initiale et CC quand il est togglé)

NUM_ENIGME = 2

# Valeur de départ pour les switchs [SW0, SW1, SW2, SW3]
VALEUR_SWITCHES_INIT = [True, True, False, True]

# Valeur finale attendue pour les switchs [SW0, SW1, SW2, SW3] - Utilisée pour vérifier si la séquence a été correctement suivie
VALEUR_SWITCH_FIN = [False, True, False, False]

# Séquence attendue pour les switchs (0, 1, 2, 3 correspondent aux indices des switchs à toggler)
SEQUENCE_ATTENDUE = [0, 1, 0, 2, 2, 3, 0, 1]

# Messages à envoyer pour les animations des bandes LED
MSG_LED_TOUT_ROUGE = 0
MSG_LED_ECHEC = 1
MSG_LED_REUSSI = 2
MSG_LED_VERT = [3, 4, 5, 6, 7, 8, 9, 10, 11] # Pour allumer la première DEL en vert, puis les deux premières, etc. jusqu'à toutes les DELs en vert




#---------------------------------------------------------------------------------------------------------------------------------------#
#                                                                                                                                       #
# Configuration logicielle                                                                                                              #
#                                                                                                                                       #
#---------------------------------------------------------------------------------------------------------------------------------------#

# Debug mode configuration
DEBUG_MODE = True  # Change to False to disable debug messages

# I2C Configuration
ADDR_ESP_DEMANDE = 0x10
NOM_ESP_DEMANDE = "IO"
VALEUR_CLE = "SW"
NB_MODULES = 4
TEMPS_ATTENTE_ERREUR = 1 # Temps d'attente en secondes en cas d'erreur de lecture I2C ou de décodage JSON, peut être ajusté selon les besoins

ADDR_ESP_COMMANDE = 0x12



#---------------------------------------------------------------------------------------------------------------------------------------#
#                                                                                                                                       #
# Hardware component pin definitions                                                                                                    #
#                                                                                                                                       #
#---------------------------------------------------------------------------------------------------------------------------------------#

# I2C Configuration
I2C_BUS_NUMBER = 1 # Bus I2C habituel sur les Raspberry Pi (bus 1 sur la plupart des modèles pins GPIO 2 (SDA) et GPIO 3 (SCL))

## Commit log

2026-02-10 Réorganisation dans les codes
2026-02-10 Changement nom dossier des codes RaspPi
2026-02-10 Shit load de ReadMe
2026-02-10 Readme projets ESP32 wroom
2026-02-11 Nouveau code pour le RFID avec la Neo debug
2026-02-11 Nouvelle biblio pour les Strips de Neo
2026-02-12 Budget de puissance
    [Budget de puissant.xlsx]
2026-02-17 Référence
    [Budget de puissant.xlsx]
2026-02-17 Schéma
    [Alimentation.SchDoc, Budget de puissant.xlsx, Esp32_Wroom(Contrôle d'entrée.SchDoc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]
2026-02-17 Section des références
    [Budget de puissant.xlsx]
2026-02-22 Projet IO presque fini. Faut valider avec Ben et améliorer la documentation
2026-02-24 Update du PCB
    [Alimentation.SchDoc, Esp32_Wroom(Contrôle d'entrée.SchDoc, Esp32_Wroom(Contrôle de DELs).SchDoc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]
2026-03-17 Mise à jour du schéma
    [Alimentation.SchDoc, Esp32_Wroom(Contrôle d'entrée.SchDoc, Esp32_Wroom(Contrôle de DELs).SchDoc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]
2026-03-17 Ajout de dossier
    [Alimentation.SchDoc, Esp32_Wroom(Contrôle d'entrée.SchDoc, Esp32_Wroom(Contrôle de DELs).SchDoc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]
2026-03-17 RFID Board
    [TEMPLATE_Circuit.SchDoc, TEMPLATE_PCB_2L.PcbDoc, TEMPLATE_Title.SchDoc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]
2026-03-18 ESP-IO et Enigme_2_NEO : ajout des fichiers de base pour les projets ESP32, avec une structure de dossiers organisée et des fichiers README pour chaque section. Les projets sont prêts à être développ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
2026-03-18 test excel
    [temps_mesures.csv, temps_mesures_v2.csv]
2026-03-18 test v_3
    [temps_mesures_v2.csv]
2026-03-18 test vitesse
    [temps_mesures_v2.csv]
2026-03-18 retire csv
    [temps_mesures_v2.csv]
2026-03-18 Create DigiKey - Print.pdf
2026-03-21 Différents mélanges de couleur
2026-03-26 Add RaspPi switch puzzle & update ESP32 LED test
    Add new Raspberry Pi switch puzzle module (Config.py, Enigme1_V2.py, Log.py) implementing I2C-based switch reading, JSON decoding, sequence logic, and logging. Update ESP32 test sketch (main.cpp) to 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
2026-03-29 Ménages dans les codes des ESP32
2026-03-29 Ajout et modifications de readme
